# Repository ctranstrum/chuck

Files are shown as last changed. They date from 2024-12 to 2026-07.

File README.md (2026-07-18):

# Charlieflex Keyboard

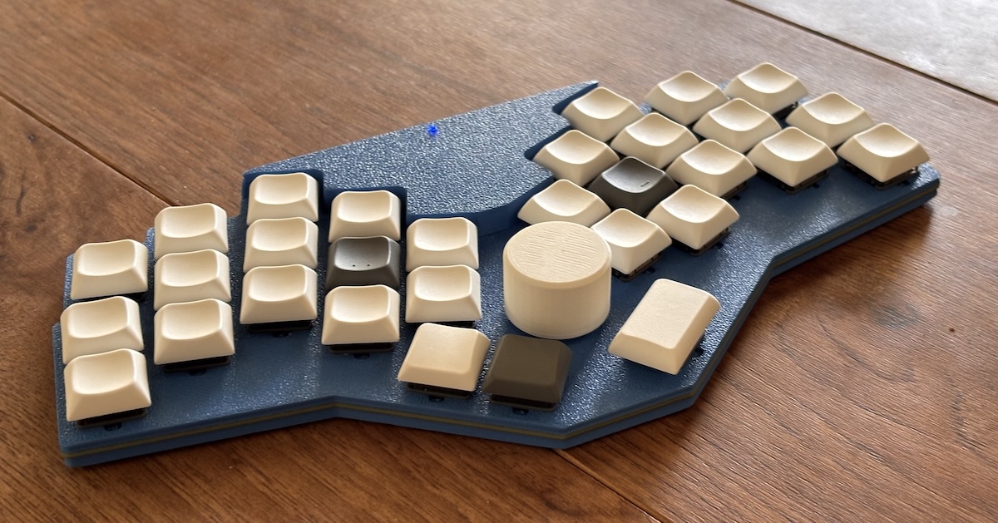
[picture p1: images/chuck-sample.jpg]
Charlieflex sample


## Features

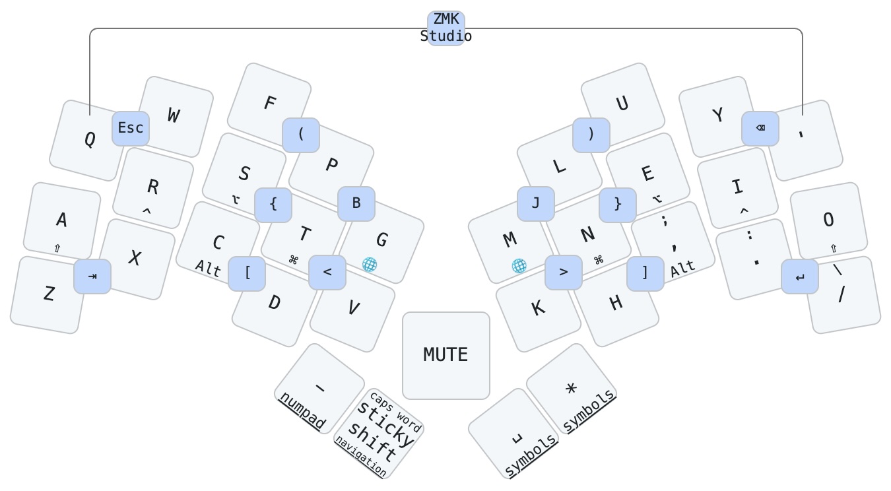
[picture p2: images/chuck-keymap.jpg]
Charlieflex keymap


- 30-32 key wireless ergo keyboard with aggressive pinky stagger and splay
- central rotary encoder can be used by either hand
- designed for the Seeed Studio [XIAO BLE][xiao] wireless microcontroller
  - also works with the [XIAO RP2040][rp2040] for a lower-cost wired board
- Choc v1 or v2 low profile hotswap switches to allow a wider range of keycap choices
- Unique tiered low-profile "snug sandwich" case with no exposed electrical components
- [RGB LED status][rgbled] visible on the top of the case
- Wireless-first design using [ZMK][zmk] [firmware][firmware] (including [ZMK Studio][studio])
- Internal space (5.5 x 27 x 32 mm) for a "large" 502530 300mAh battery
- [PCB](images/chuck-pcb.jpg) designed with [ergogen][ergogen] for easy modification
- Licensed under the [CERN Open Hardware License v2][ohl]
- All source files available, so you can tweak the design if needed

## Design goals

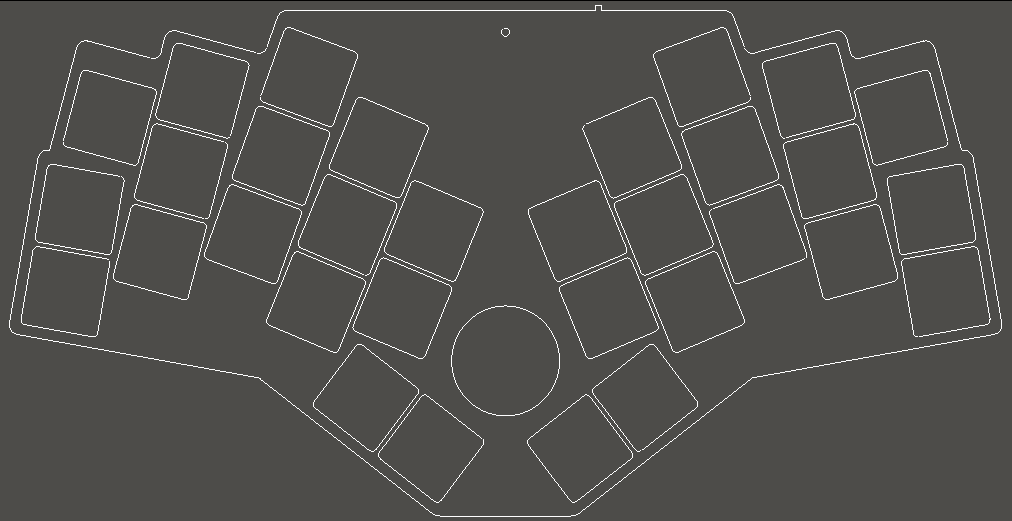
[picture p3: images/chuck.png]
Charlieflex Layout


- Low cost wireless
  - xiao ble is only $10 per controller compared to $25 for the nice!nano
  - Big battery and an option for a dongle, so you can run for months without recharging
  - xiao rp2040 is under $5 with no need to purchase a battery or power switch if you want a wired board
- Ergonomic unibody design for the ultimate comfort and easy portability
  - each half is angled to match the angle of the hands on the board
  - keys are placed where fingers naturally fall, with no excessive stretching
    - 1DFH: no finger has to move farther than 1 key's distance from its home row position
    - when fingers extend, they splay, so the keys also splay outward to follow the fingers
    - the pinky is shorter than the other fingers, so the pinky keys are placed lower to match, and the top pinky key is traded for a ring finger key
    - the inner column of each hand is reduced to two keys to eliminate the need for index finger stretching
    - each thumb gets a single key, with an option for a secondary thumb key if your thumbs are smarter than mine
  - centrally located rotary encoder knob for easy ambidextrous access to scrolling and volume control
  - includes all source files, so if your fingers are slightly different, with a little work you can adjust the keyboard to fit you exactly

finger map

- Low profile [3D printable case][case]
  - wireless case is only about 7mm high in front and 15mm high in the back, and comes in three separate pieces, each largely flat on one side for easy FDM printing with minimal fuss
  - for those who don't want or need the extra space required for a battery, a separate wired case is provided, which comes in two pieces and is just under 7mm tall
  - options for 1 or 2 thumb keys on each hand so you can go minimal if desired
  - smaller versions are included for smaller print beds
  - a few different [knobs][case-knob] are included so you can get the height that works best for you
  - bumpons are inset into the case 1mm to minimize their height; they add only 1/2mm in height
- Hotswappable
  - keycaps and switches can be easily removed and exchanged so you can fine-tune the feel
  - ability to move back and forth between or even mix and match choc v1 and choc v2
- Electrostatic mitigation
  - unlike many other ultra-low-profile cases, no electronics are left exposed
  - usb port and power switch are on the back, reset switch is recessed into the bottom of the case

## Build Guide

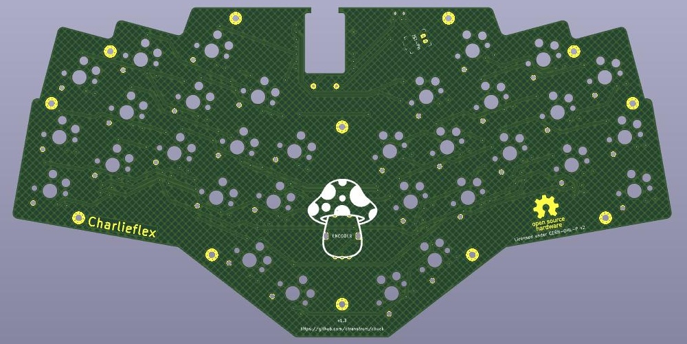
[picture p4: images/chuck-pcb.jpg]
Charlieflex PCB


Interested in building a Charlieflex of your own?
Check out the [Build Guide][guide] for details.

## Ancestry

I designed the [Lintilla keyboard][lintilla] before the Charlieflex,
but over time I realized that I didn't actually like split keyboards with separate halves,
because I move around a bit as I type so I either have to keep adjusting the position
of each half, or I end up contorting my wrists to align with the keyboard.

I also came to the conclusion that I would be better off with fewer pinky keys,
due to the strain of reaching with the pinky, and my thumbs aren't actually
smart enough for three keys each.

However, the basic layout of the remaining keys didn't change much from what
I had before, so if you want a split layout and more keys than the Charlieflex offers,
maybe the [Lintilla][lintilla] is for you.

## Descendants

I found some issues with running a charlieplex matrix on a wireless board where
battery levels can impact the performance of the diodes, which need very precise
cutoffs to interpret the keys being pressed; it made some of my 3-key combos a little
unreliable in practice.

So I went back to the drawing board and discovered an extra two usable pins on the xiao ble.
Using those allowed me to build the [Patagona gigas][patagona], with 32 keys and a five-way switch,
along with the [Patagona chaski][patagona], with 42 keys,
the same number of keys used by the [Lintilla][lintilla].

## Builds

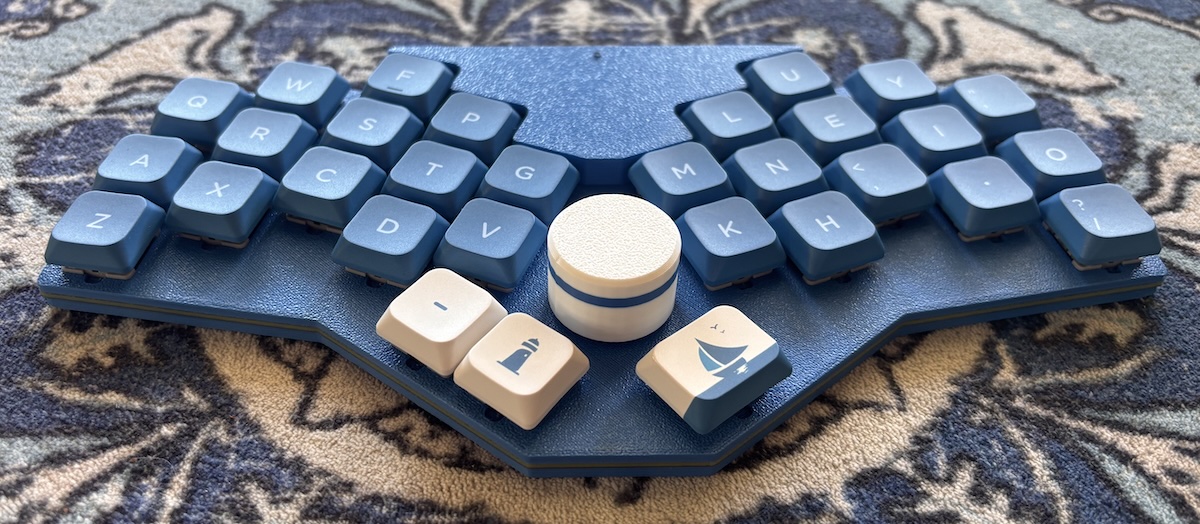
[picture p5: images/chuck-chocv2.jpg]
Charlieflex Choc v2 Keyboard


My Charlieflex, in the Twentyone Chuck Street layout, with 2 keys for the left thumb and one key for the right.
I'm using [Lofree Hades Choc v2 switches][hades]
and [Nuphy Shiokaze nSA keycaps][shiokaze].

---

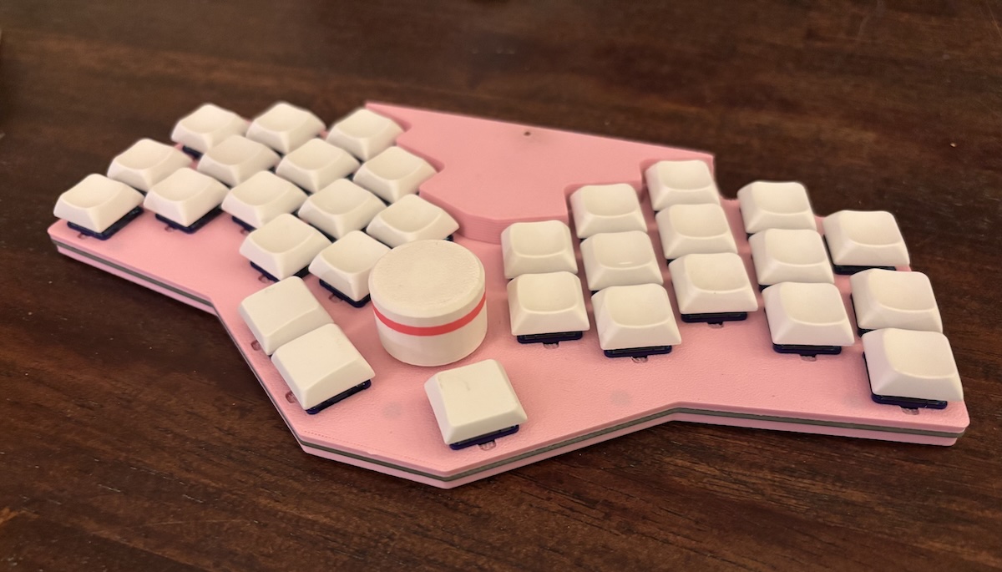
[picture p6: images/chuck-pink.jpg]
Charlieflex Choc v1 Keyboard


I also built a pink Charlieflex for the office,
this time with [LDSA keycaps][ldsa]
on [Bokeh Ambient Choc v1 switches][bokeh].

---

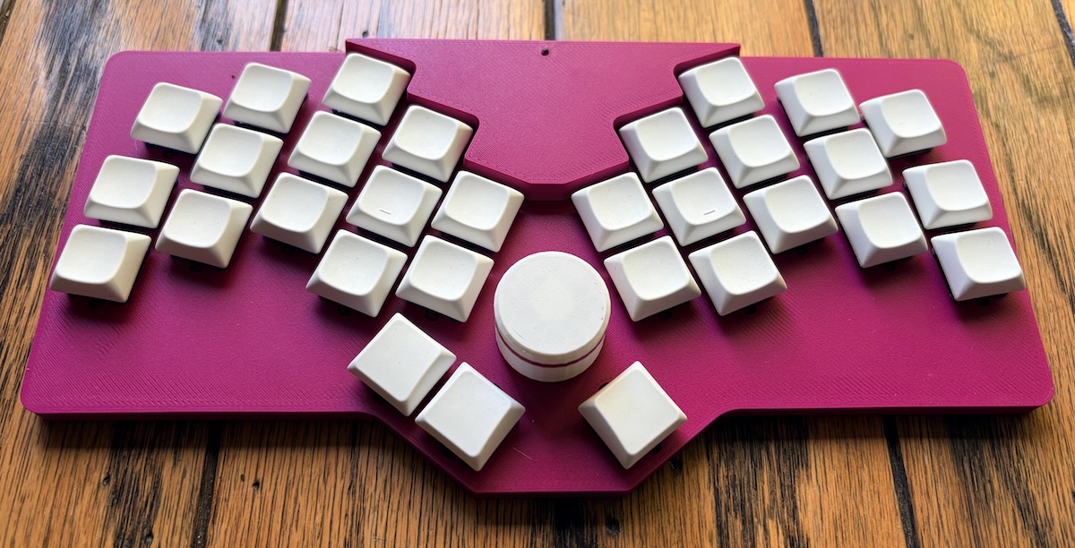
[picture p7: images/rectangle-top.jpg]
Charlieflex keyboard with rectangle case


An alternate snap-fit case that uses fewer screws and is a bit more stable
if you tend to use the keyboard directly on your lap.

[ergogen]: https://ergogen.xyz
[bokeh]: https://lowprokb.ca/products/ambients-silent-choc-switches?variant=51042310062244
[case]: cases#readme
[case-knob]: cases#encoder-knobs
[firmware]: https://github.com/ctranstrum/chuck/tree/zmk
[guide]: BUILD.md
[hades]: https://www.lofree.co/products/hades-low-profile-pom-switches
[ldsa]: https://lowprokb.ca/collections/keycaps/products/ldsa-low-profile-blank-keycaps
[lintilla]: https://github.com/ctranstrum/lintilla
[ohl]: LICENSE.txt
[patagona]: https://github.com/ctranstrum/patagona
[rgbled]: https://github.com/caksoylar/zmk-rgbled-widget
[rp2040]: https://www.seeedstudio.com/XIAO-RP2040-v1-0-p-5026.html
[shiokaze]: https://nuphy.com/collections/keycaps/products/shiokaze-nsa-dye-sub-pbt-keycaps
[studio]: https://zmk.dev/docs/features/studio
[twilight]: https://lowprokb.ca/products/ambients-silent-choc-switches?variant=44873426436260
[xiao]: https://wiki.seeedstudio.com/XIAO_BLE/
[zmk]: https://zmk.dev

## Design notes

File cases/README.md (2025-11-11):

# Charlieflex Cases

> A quick note: these files were created through ergogen and can be
> modified and re-created if any changes are needed, which is great,
> except that the software is still a little bit buggy, so it doesn't
> make perfect STL files. Even though these can look a little strange,
> I have printed all of these files and they came out okay for me.

## Keyboard case files

### Full size printer

If you have access to your own 3D printer with a large print bed
or if you are sending the files away to be printed,
you will want to use the full size cases:

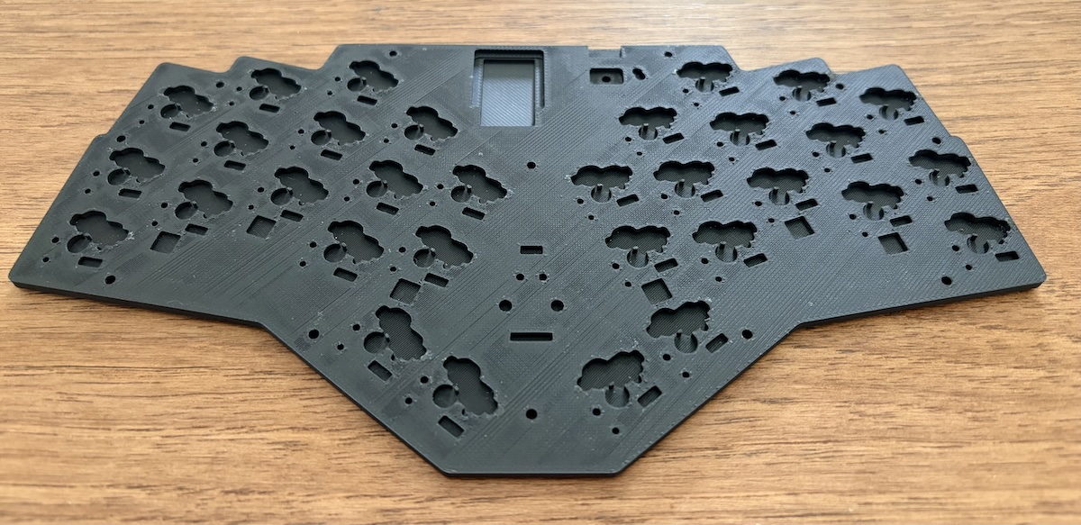
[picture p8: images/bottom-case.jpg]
bottom-case


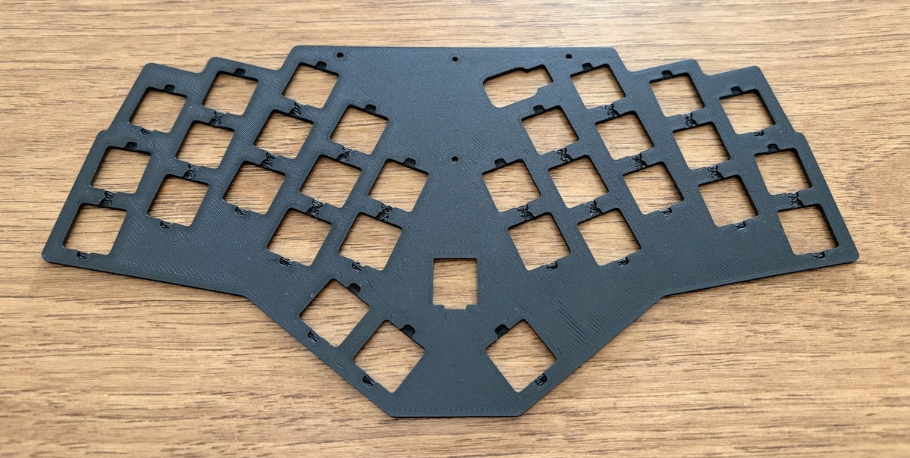
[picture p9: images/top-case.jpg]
top-case


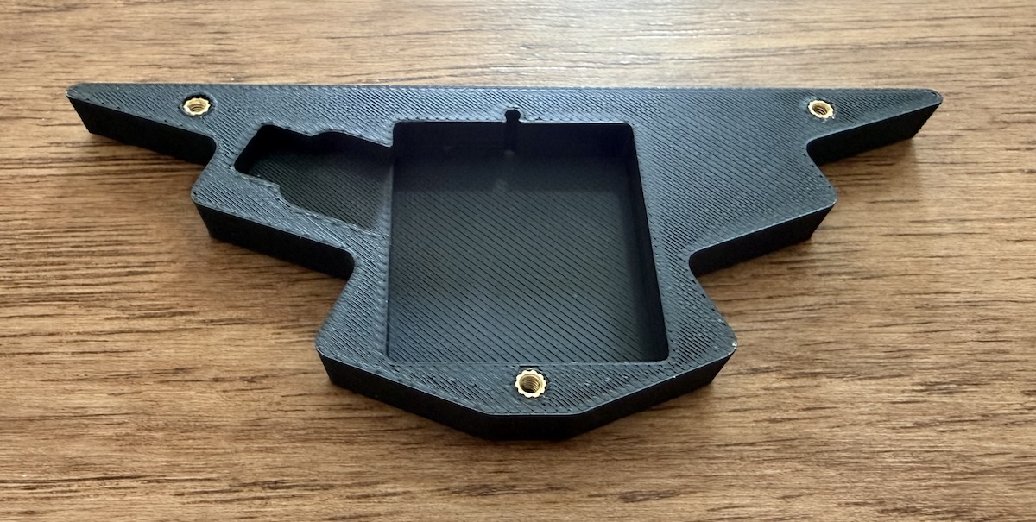
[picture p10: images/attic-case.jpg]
attic-case


| wired | wireless | description |
| --- | --- | --- |
| [bottom](wired_bottom_case.stl) | [bottom](bottom_case.stl)  | installed below the PCB |
| [top](wired_top_case.stl) | [top](top_case.stl) | installed above the PCB for two thumb keys on each side |
| | [battery cover](attic.stl) | above the top plate (do not print in resin) |

There are three alternative top cases that can be used
depending on the number of thumb keys used on each hand:

| wired | wireless | description |
| --- | --- | --- |
| [one up chuck](wired_top_case_one_up_chuck.stl) | [one up chuck](top_case_one_up_chuck.stl) | one thumb key on each hand |
| [twentyone chuck street](wired_top_case_twentyone_chuck_street.stl) | [twentyone chuck street](top_case_twentyone_chuck_street.stl) | two thumb keys on the left hand and one on the right |
| [chucker by the dozen](wired_top_case_chucker_by_the_dozen.stl) | [chucker by the dozen](top_case_chucker_by_the_dozen.stl) | one thumb key on the left hand and two on the right  |

Note that for best results on an FDM printer, the top plate and the battery cover should be printed upside down.

### Mini printer

If you have access to your own 3D printer
but it has a print bed too small for the full-size case,
you can print the 3-part (plus the battery cover for wireless builds) top case:

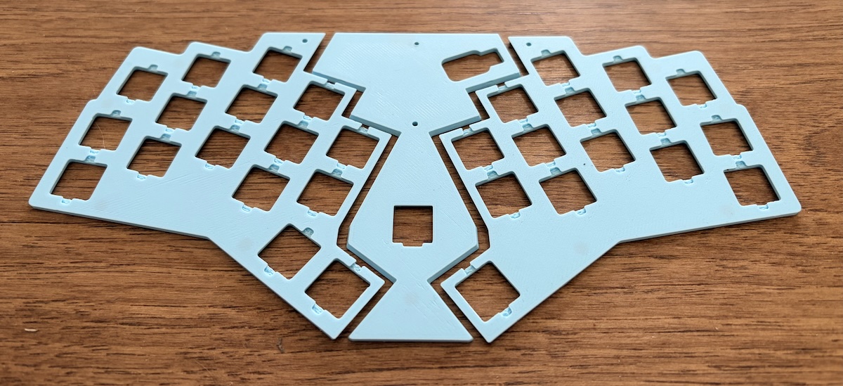
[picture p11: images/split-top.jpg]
split-top


| wired | wireless | description |
| --- | --- | --- |
| [center](wired_top_dovetail.stl) | [center](top_dovetail.stl) | center dovetail piece |
| [left 1](wired_top_dovetail_left_1.stl) | [left 1](top_dovetail_left_1.stl) | left piece with one thumb key |
| [left 2](wired_top_dovetail_left_2.stl) | [left 2](top_dovetail_left_2.stl) | left piece with two thumb keys |
| [right 1](wired_top_dovetail_right_1.stl) | [right 1](top_dovetail_right_1.stl) | right piece with one thumb key |
| [right 2](wired_top_dovetail_right_2.stl) | [right 2](top_dovetail_right_2.stl) | right piece with two thumb keys |
| | [battery cover](attic.stl) | above the top plate to cover the battery (do not print in resin) |

Note that these top cases should be printed upside down for best results on an FDM printer.

The bottom case is broken into two pieces:

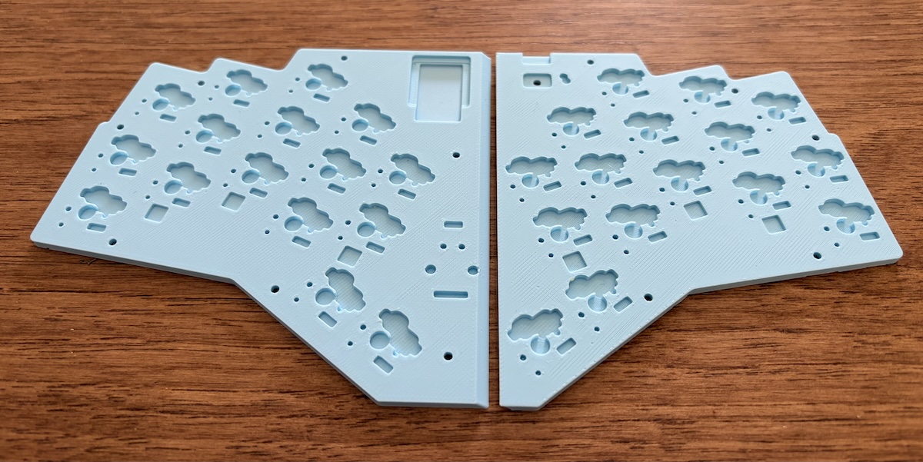
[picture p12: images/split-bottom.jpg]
split-bottom


| wired | wireless | description  |
| --- | --- | --- |
| [left](wired_bottom_dovetail_left.stl) | [left](bottom_dovetail_left.stl) | left bottom  |
| [right](wired_bottom_dovetail_right.stl) | [right](bottom_dovetail_right.stl) | right bottom |

### Rectangular snap-fit case

I've also created an alternative case that uses fewer screws and instead relies on a snap-fit design
to remain securely fastened without sacrificing any additional height compared to the original sandwich design.

rectangle-top

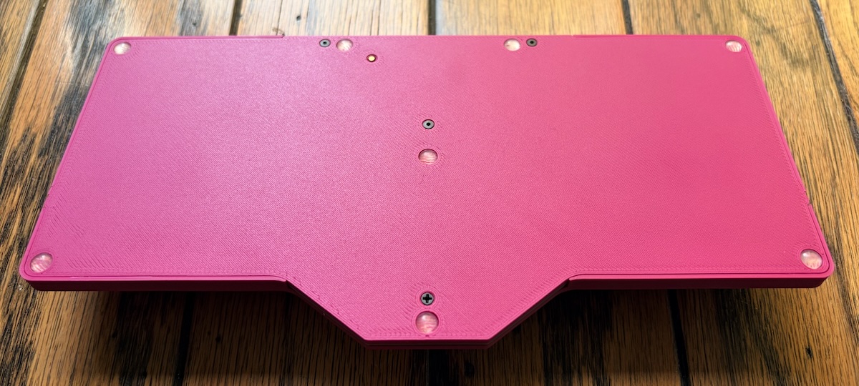
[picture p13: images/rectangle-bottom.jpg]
rectangle-bottom


Unlike the sandwich-style cases, it is available only for full-size printer beds,
and only for a wireless build.

| wireless | description |
| --- | --- |
| [bottom](rectangle_bottom_case.stl) | bottom case |
| [top](rectangle_top_case.stl) | top case option with two thumb keys on each hand |
| [one_up_chuck](rectangle_top_case_one_up_chuck.stl) | top case option with one thumb key on each hand |
| [twentyone_chuck_street](rectangle_top_case_twentyone_chuck_street.stl) | top case option with two left thumb keys and one right thumb key |
| [chucker_by_the_dozen](rectangle_top_case_chucker_by_the_dozen.stl) | top case option with one left thumb key and two right thumb keys |
| [battery cover](attic.stl) | above the top case to cover the battery (do not print in resin)  |

Note that it is especially important when printing this case style on an FDM printer to place the top case
upside down in the slicer so that the top surface of the case is in direct contact with the print bed.
Otherwise you are going to have a real struggle with support removal.

## Print quality hints

When printing this case,
it should be noted that the battery cover (filename: `attic.stl`) is designed
to have heat-set inserts melted into it,
so it is not recommended to print using a resin printer
or using a material that cannot be melted easily,
unless you plan on altering the case design to use another method
to fasten the case together.

All other parts of the case can be printed in whatever material you like.

For FDM printing,
the top case and the attic are best printed upside down,
so that the visible part of the case is against the print bed,
giving the best top surface and requiring minimal supports to print.

If you are having trouble with some of the raised areas sagging during printing,
you can try to enable supports.
While I was able to tune my printer to get great results without supports,
if your printer is not well calibrated,
it may be worth it to enable supports and spend a little time
post-processing the prints to remove the supports prior to assembly.

## Encoder knobs

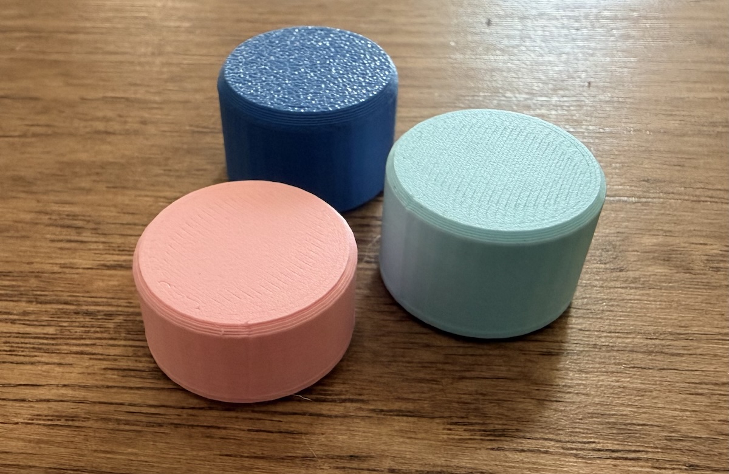
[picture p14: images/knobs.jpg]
knobs


The keyboard was designed with the idea of using a 25mm diameter knob,
but I had a hard time finding encoder knobs that size,
especially for an EC12 low-profile encoder.

If you use the recommended EC11 encoder,
you should have plenty of commercially available options for the knob,
so feel free to use whatever knob you like.

But I've also created a super-simple one with a skirt
so that as much of the encoder as possible is hidden.

- [ec11_encoder_knob.stl](ec11_encoder_knob.stl)
- [ec12_encoder_knob.stl](ec12_encoder_knob.stl)

Both of those knobs will give about the same look,
but if you use a low-profile EC12 knob,
you have the ability to go with a shorter knob:

- [encoder_knob-15mm.stl](encoder_knob-15mm.stl)
- [encoder_knob-13mm.stl](encoder_knob-13mm.stl)
- [encoder_knob-10mm.stl](encoder_knob-10mm.stl)

All of the encoder files can be printed as-is with no supports.

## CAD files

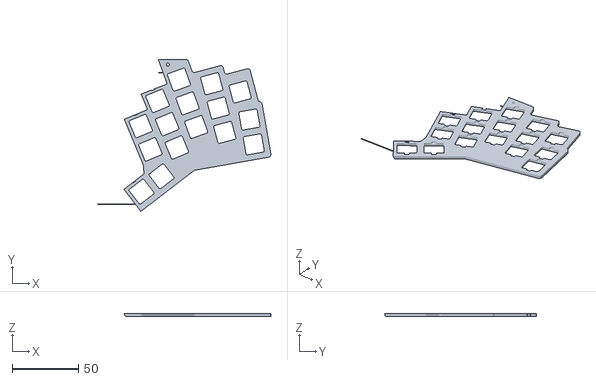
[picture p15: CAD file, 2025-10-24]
cases/top_dovetail_right_2.stl
163.7 x 114.5 x 2.20

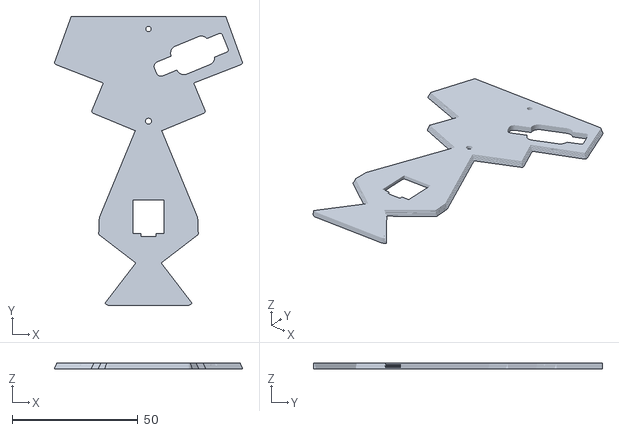
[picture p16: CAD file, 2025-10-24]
cases/top_dovetail.stl
74.7 x 114.9 x 2.20

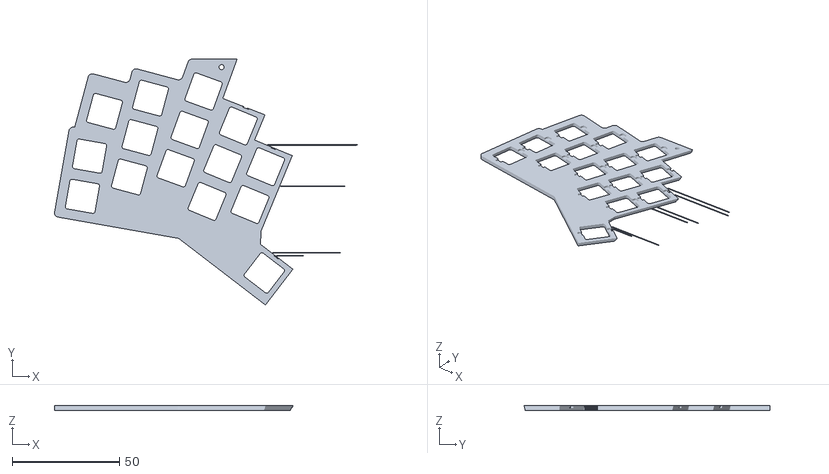
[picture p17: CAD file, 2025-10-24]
cases/top_dovetail_left_1.stl
165.7 x 114.5 x 2.20

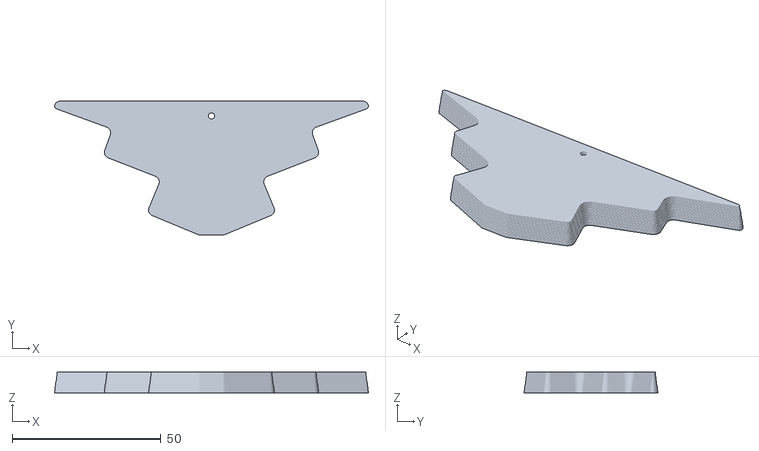
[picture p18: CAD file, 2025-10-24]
cases/attic.stl
105.5 x 45.0 x 7.00

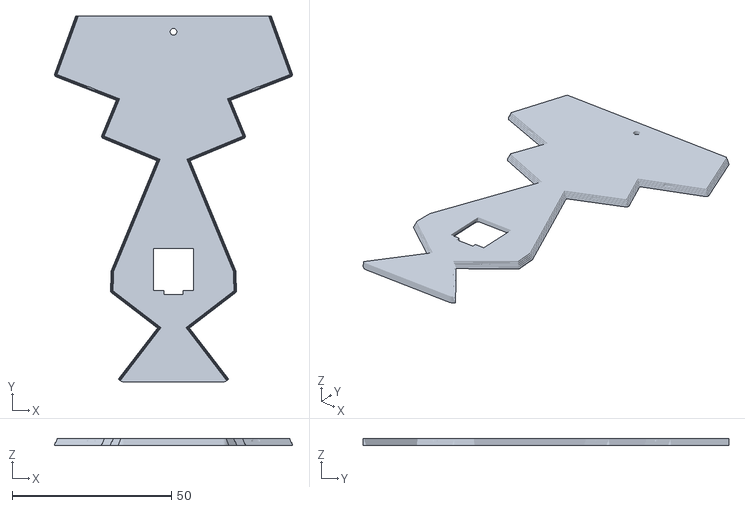
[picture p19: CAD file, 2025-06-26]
cases/wired_top_dovetail.stl
74.7 x 114.9 x 2.20

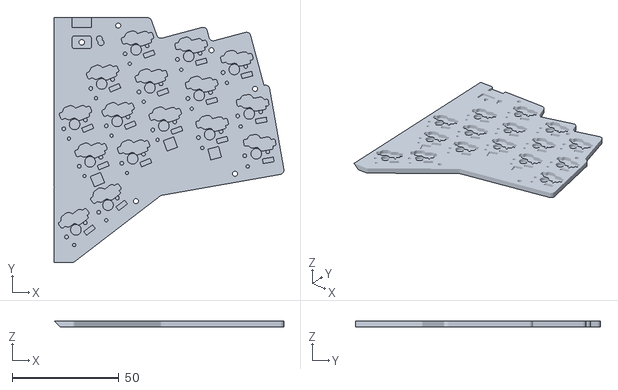
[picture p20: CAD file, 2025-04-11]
cases/bottom_dovetail_right.stl
107.9 x 114.9 x 3.00

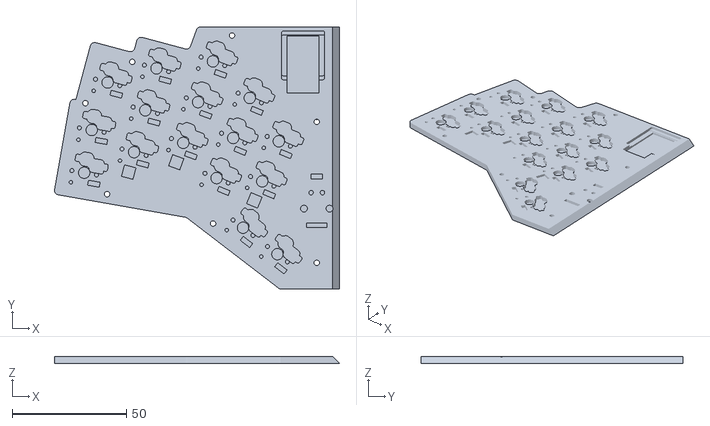
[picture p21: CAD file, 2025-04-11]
cases/bottom_dovetail_left.stl
124.8 x 114.9 x 3.00

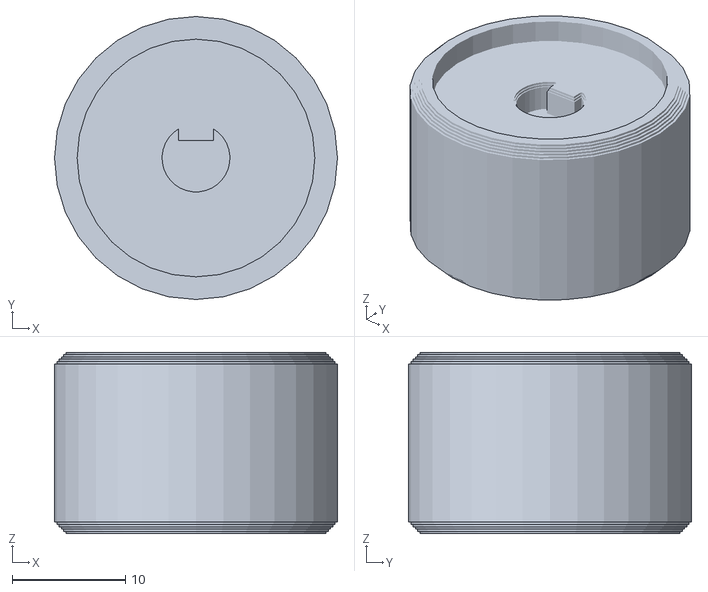
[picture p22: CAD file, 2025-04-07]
cases/ec12_encoder_knob.stl
25.0 x 25.0 x 16.0

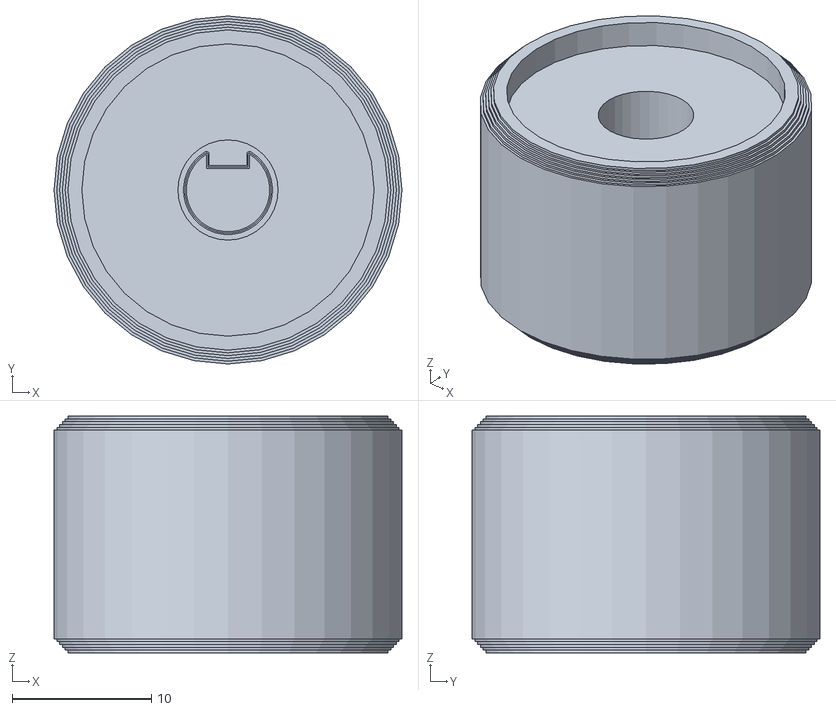
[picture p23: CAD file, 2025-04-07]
cases/ec11_encoder_knob.stl
25.0 x 25.0 x 17.0

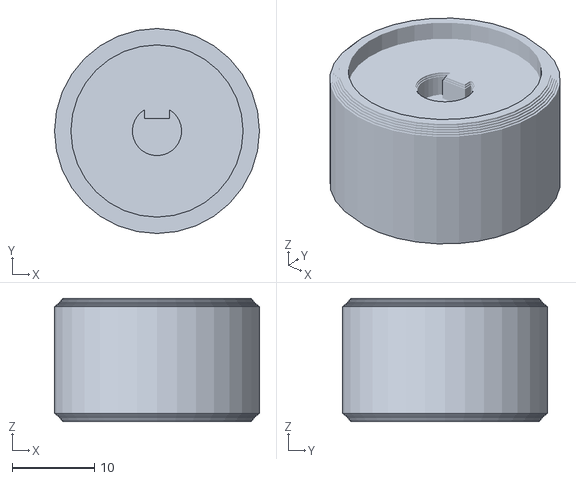
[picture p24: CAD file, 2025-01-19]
cases/encoder_knob-15mm.stl
25.0 x 25.0 x 15.0

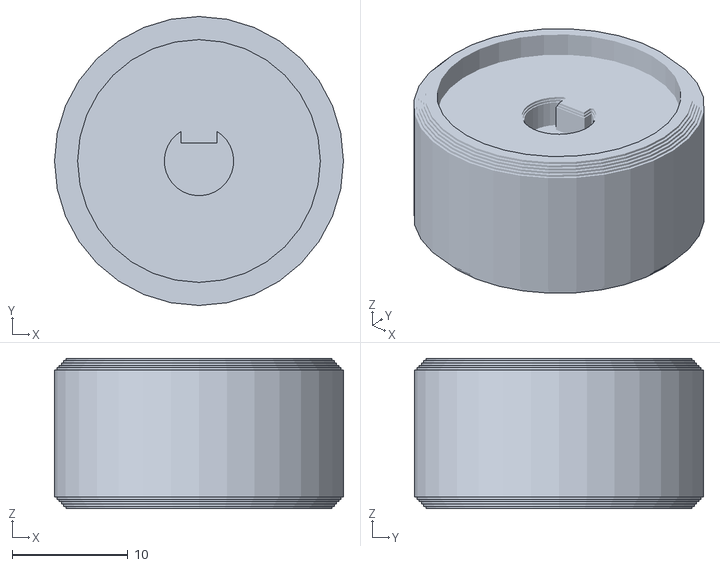
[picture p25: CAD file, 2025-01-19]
cases/encoder_knob-13mm.stl
25.0 x 25.0 x 13.0

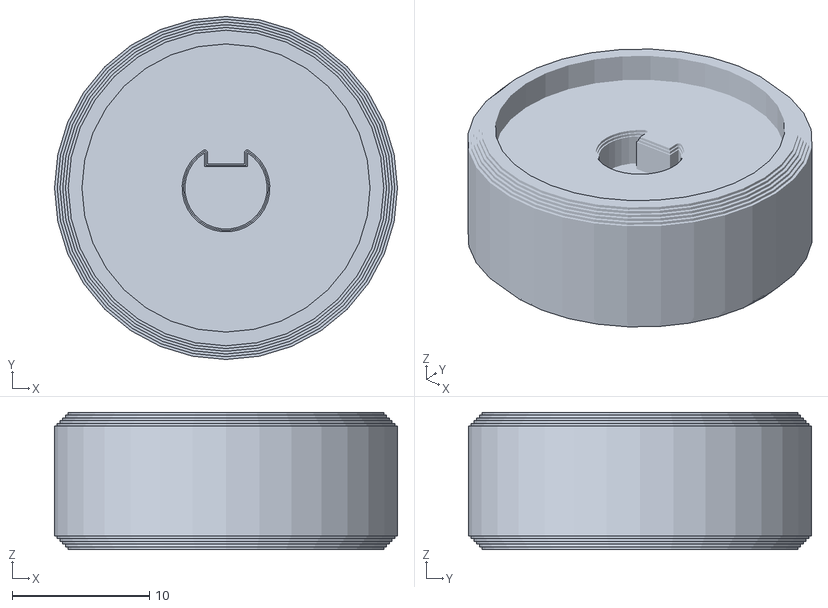
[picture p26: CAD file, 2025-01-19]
cases/encoder_knob-10mm.stl
25.0 x 25.0 x 10.0

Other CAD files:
cases/top_dovetail_left_2.stl
cases/top_dovetail_right_1.stl
cases/wired_top_dovetail_left_2.stl
cases/wired_top_dovetail_right_1.stl
cases/wired_top_dovetail_left_1.stl
cases/wired_top_dovetail_right_2.stl

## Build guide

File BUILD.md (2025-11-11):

# Charlieflex Build Guide

If this is your first time building a custom keyboard,
you should do two things before attempting this build.

- watch a few [soldering][how-to-solder] [tutorials][soldering101]
- read through a detailed build guide like
  the one for the [splitkb.com Aurora Series][splitkb-build-guide]

The remainder of this build guide will assume a basic familiarity with the process
and will only hit upon specific items that may be different or important to note while
building the Charlieflex.

## Bill of materials

| Wireless Qty | Description | Wired Qty |
| --- | --- | --- |
| 1 | [Charlieflex PCB][pcb] (can be printed by uploading the [zip file][gerber] to [JLC][jlcpcb]) | 1 |
| 3 | [3D printed cases][case] | 2 |
| 1 | [XIAO BLE][xiao] | |
| | [XIAO RP2040][rp2040] | 1 |
| 1 | [SMD 5x5x3 tactile switch][reset] for the reset button (similar to [this][pts526] or [this][ts18]) | 1 |
| 1 | [Alps SSSS811101 SPDT slide switch][power] for the battery on/off | |
| 1 | [3.7v 300mAh 502530 LiPo battery][battery] or smaller (max internal space: 5.5x27x32mm) | |
| 1 | [JST PH-2 battery jack][jst] | |
| 45 | SOD-123 [1N4148W SMD diodes][sod123] | 45 |
| 30-32 | Kailh [choc hot swap sockets][sockets] | 30-32 |
| 30-32 | [Choc v1][chocv1] or [v2 switches][chocv2] of your choice | 30-32 |
| 30-32 | [Low profile choc v1][chockeycaps] or [v2 keycaps][mxkeycaps] of your choice | 30-32 |
| 1 | Bourns [PEC11L-4115F-S0020][encoder]\* EC11 encoder with a [knob][case-knob] of your choice | |
| | Bourns [PES12-42S][smallencoder] low profile EC12 encoder with a [knob][case-knob] of your choice  | 1 |
| 9 (1) | [M2 x 6mm countersunk screws][screws6mm] | 12 |
| 9 (1) | [M2 hex nuts][hexnuts] | 12 |
| 3 | [M2 x 10mm countersunk screws][screws10mm] | |
| 3 | [M2 heat-set inserts 3mm x 3mm][heatset] | |
| 10 (8) | [6mm x 1.5mm bumpons][bumpons] | 10 |
| ~1cm | [1.75mm transparent 3D printer filament][filament] for the "fiber optic" led light guide | ~3mm |
| 2 | short (1-2cm) piece of [26 gauge electrical wire][wire] | 1 |

\* You can use a different encoder from another manufacturer if you aren't going wireless,
but the specified wireless encoder listed in the bill of materials
is designed to have its detents with both A and B set to low,
so a different option is likely to draw more power,
and thus isn't the best choice for a wireless build.

**Note**: When assembling a Charlieflix build in a rectangle case, you will use fewer 6mm screws, hex nuts, and bumpons.
The quantities for the rectangle case are given in parentheses.

## Useful equipment

You will need:

- a [soldering iron][pinecil]
- some [good quality solder][kester]
- precision tweezers
- wire cutter / stripper

You should ideally have access to:

- a [heat-set insert tool][heatsettool]
- a decent hands-free magnifying glass
- isopropyl alcohol and an old toothbrush

## Getting the PCB

The PCB can be easily ordered from a circuit board manufacturer with an online store.
I used [JLC][jlcpcb] because--at least at the time of my order--their prices are unbeatable.

To order, you can simply upload the [gerber zip file][gerber] to their website,
accept all of the defaults, and wait a week or two for the boards to arrive.

However, the minimum order at JLC is 5 copies, so you'll likely end up
with 4 extra PCBs. I don't really have any advice for what to do with
the extras, but you maybe could give one to a friend!

A few items that you may want to customize:

- the color of the board; I printed mine in blue
- I also chose to hide the JLC order number, to give the board a cleaner look
- HASL can be lead-free if you are also using lead-free solder, or you can splurge for ENIG, but it's definitely not required

## Getting the case

If you have access to a 3D printer, the [case][case] is very easy to print yourself.
If you have a Bambu printer, I uploaded printer profiles to their [makerworld][bambu] website.

If you don't have your own printer, no worries.
You will probably want to send in your print order around the same time you order the PCB.
I've used [JLC][jlc3dp] in the past with good results.

Just remember that you should print the top-most piece of the case,
called "attic" in the [case list][case] and needed only for a wireless build,
in nylon or PLA rather than resin,
though all other parts of the case can be printed in resin.
The reason for this is that the design calls for heat-set inserts
to be melted into that piece, and resin doesn't work for that.

## General soldering order

Although you can work in any order you prefer,
I like to start with the smaller components, then move to the larger,
and finish with bulky items that go on the top of the board.

So, the order I install:

### Installed on the bottom of the board

- diodes
- hotswap sockets
- power switch
- reset switch
- xiao
- reset and battery wire connections to xiao

### Bulky items, assembled on the top of the board, but soldered on the bottom

- jst
- encoder

## Step-by-step instructions

Let's get started, shall we?

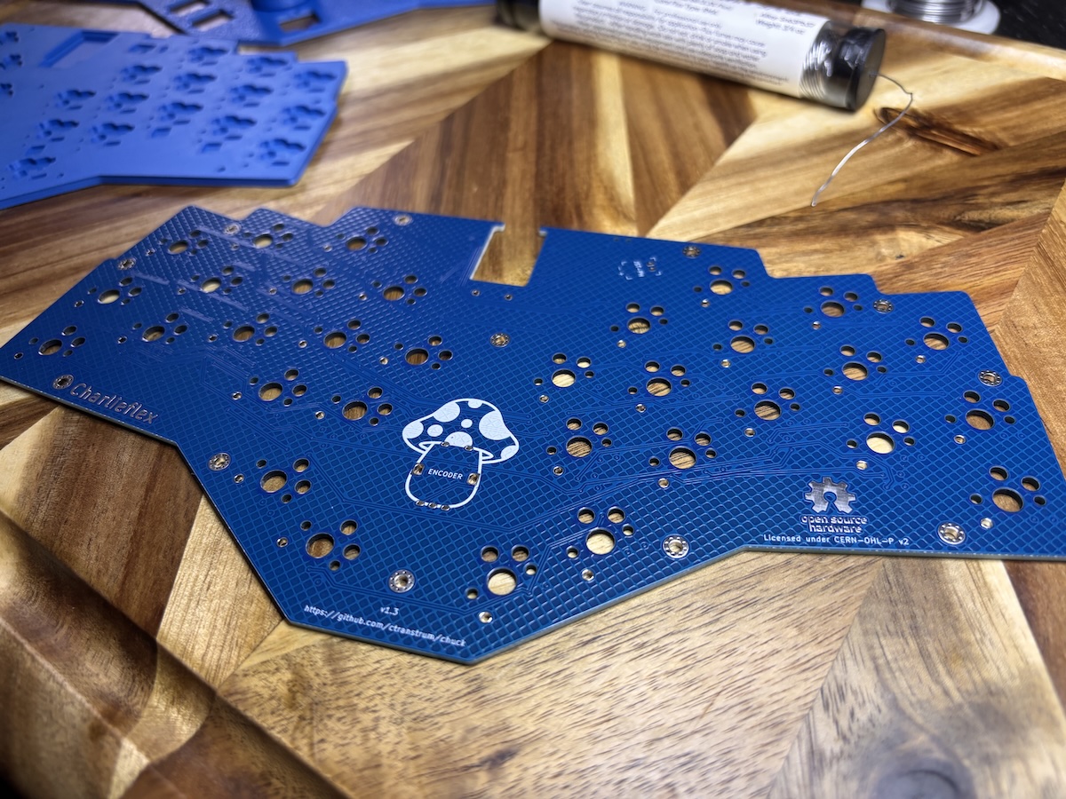
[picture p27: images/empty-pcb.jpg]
empty pcb


### Solder the diodes

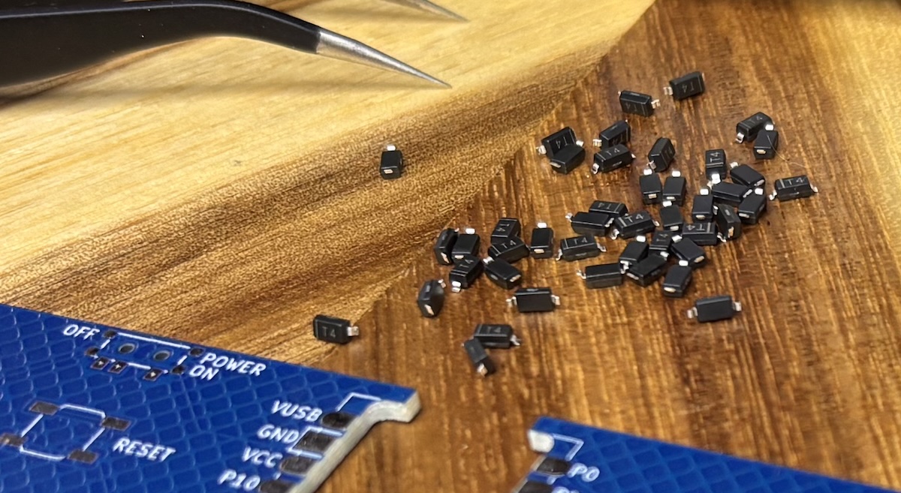
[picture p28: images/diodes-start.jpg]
start with diodes


Diodes are directional components, and must be soldered in the correct orientation.

To determine the orientation, look for a line printed on one edge of the diode.
You may need to use a magnifier glass and adjust the angle of light hitting the diode
in order to see it clearly.
Once you find the line on the diode, you can align it with the silk-screened line on the PCB,
and then solder with both lines on the same side.

All diodes are installed in roughly the same direction on the board, with the line on the right.

To easily install a diode, first place a small amount of solder onto one of the diode pads.

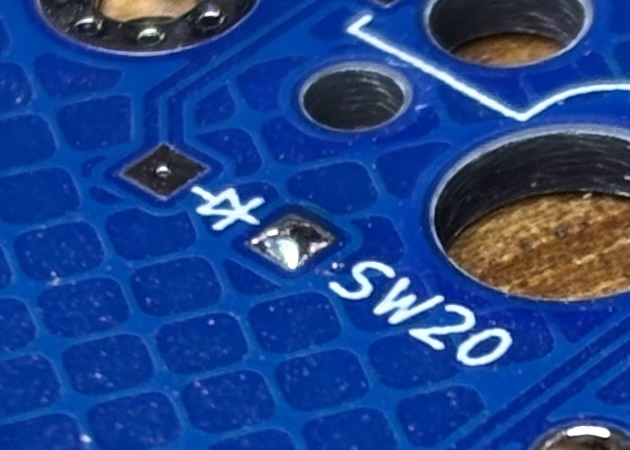
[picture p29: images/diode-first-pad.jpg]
first pad soldered


Then grab the diode with tweezers and orient it correctly.
Reheat the soldered pad, then slide the diode into place.
Remove the heat, and when the solder cools, release the diode.

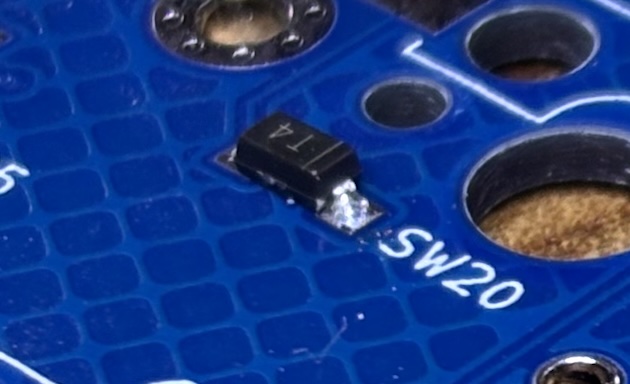
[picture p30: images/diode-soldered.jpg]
diode soldered


With one leg installed, you can apply solder to the other leg.

Complete all diodes, being sure to double-check that they are all oriented
correctly and both legs are soldered before moving to the next step.

### Solder the hotswap sockets

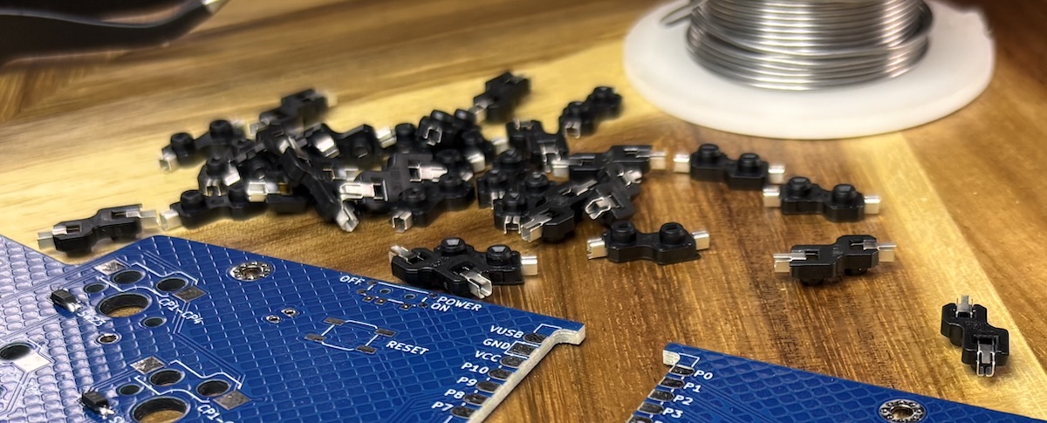
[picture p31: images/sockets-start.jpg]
start with sockets


While hotswap sockets will work the same way electrically no matter which way they are installed,
the tolerances of the case are such that you should take care to install these
according to the markings on the PCB as well.

Place the hotswap socket into the PCB holes,
being sure that the silkscreen on the PCB matches the orientation of the socket,
then apply solder to one of the legs.

This will take a lot more solder than the diode did, but be careful not to get carried away.
The solder should not overflow the pad or rise above the socket.

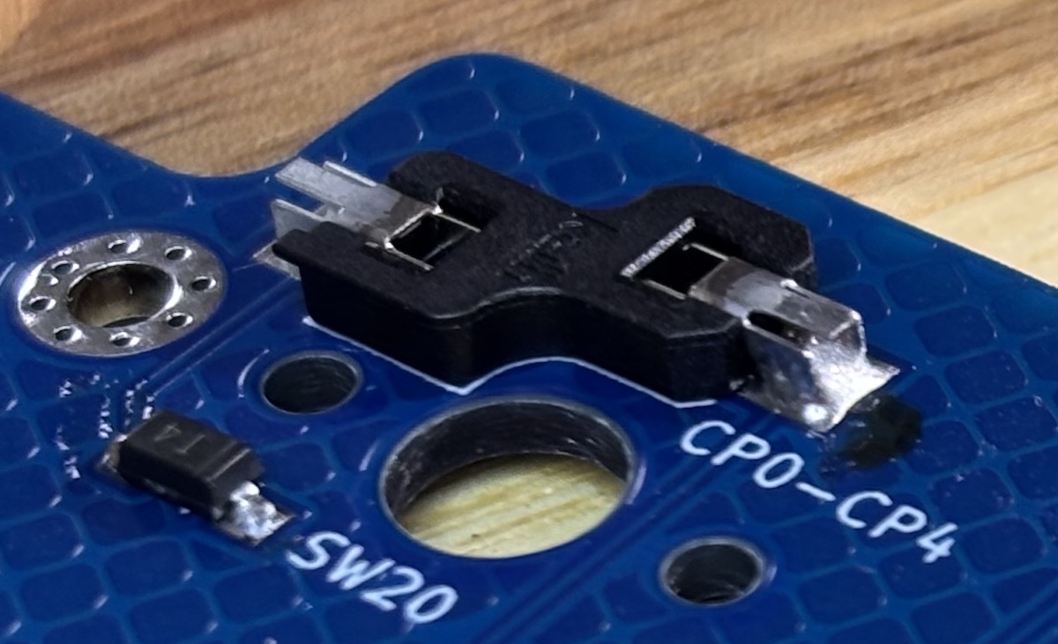
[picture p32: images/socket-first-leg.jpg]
first pad soldered


Once done, use tweezers to hold the socket in place until the solder cools.

Flip the board around and solder the other pad.

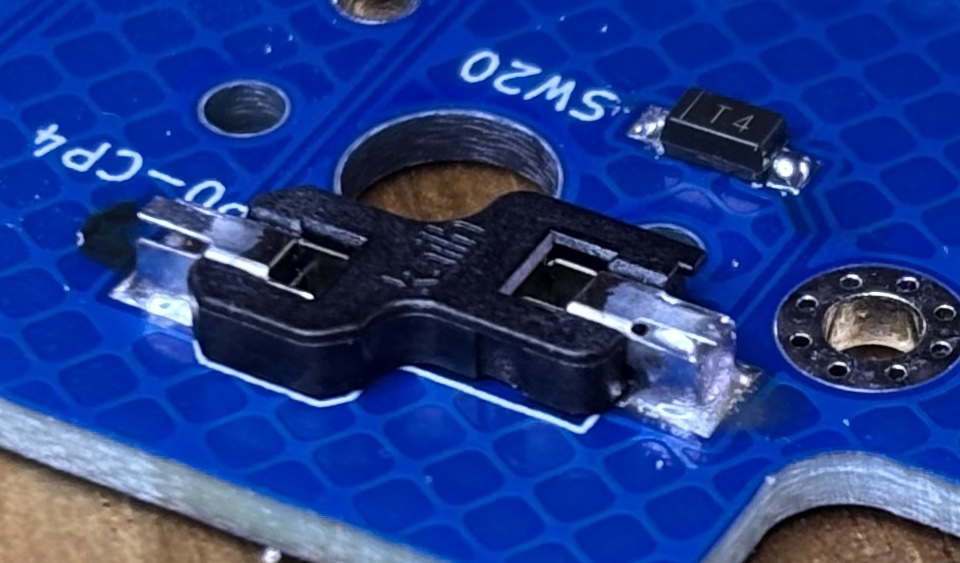
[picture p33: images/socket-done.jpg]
socket completed


Solder all the sockets on the board.

### Solder the power switch

_Note_: you should skip this step if you are not building a wireless keyboard.
A wired keyboard is powered by the USB from the computer,
so doesn't need a power switch.

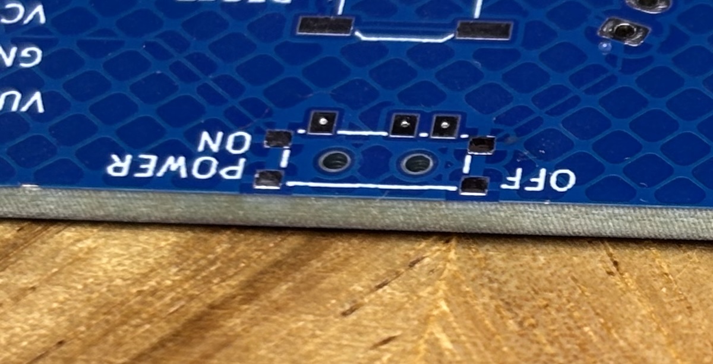
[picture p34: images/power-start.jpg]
start power


To solder the power switch, first apply a bit of solder to one of the pads.

Holding the power switch in place with tweezers, reheat the soldered pad
and align the power switch. Remove the heat, and release the power switch
only after the solder has cooled.

Once satisfied with the placement, solder each of the other pads, being very careful
not to allow the solder to connect neighboring pads.

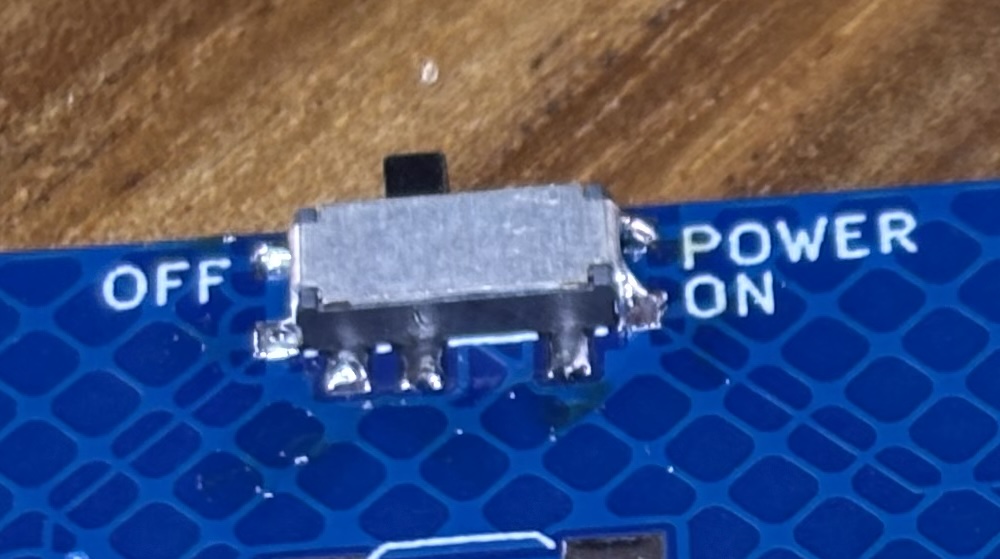
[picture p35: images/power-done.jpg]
power complete


### Solder the reset switch

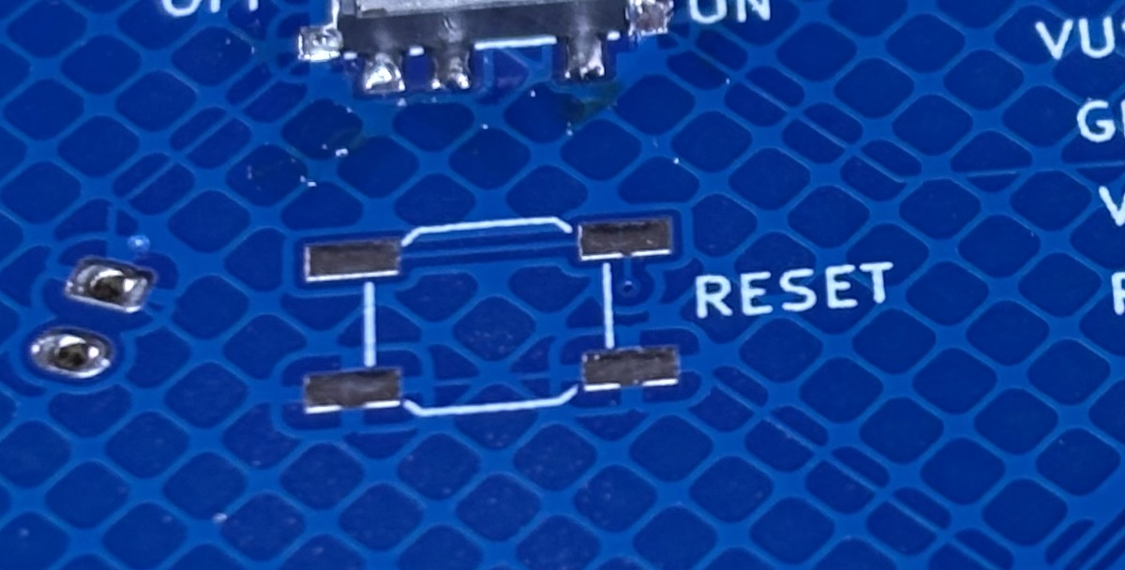
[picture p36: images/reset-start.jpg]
start reset


The reset switch follows the same process,
though it can require a little more attention to align it correctly.

Apply solder to one pad,
use tweezers to slide the reset switch into place while reheating the solder,
and remove the heat when you are satisfied with the alignment.

Complete the remaining pads.

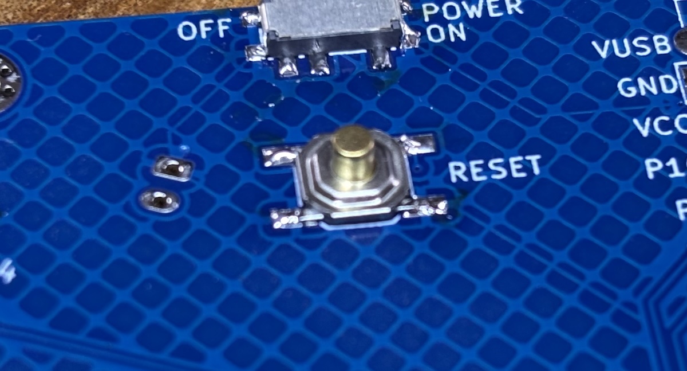
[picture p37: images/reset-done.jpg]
reset complete


### Solder the xiao

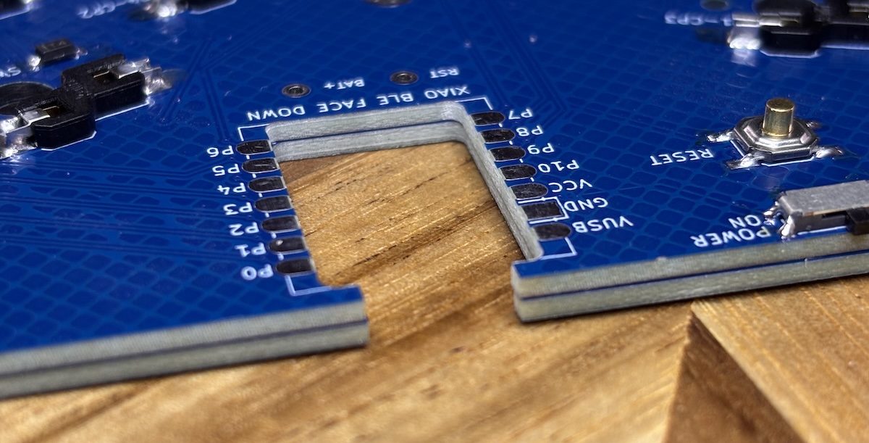
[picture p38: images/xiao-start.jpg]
start xiao


The xiao is installed upside down,
with the components on top of the xiao extending
into and beyond the space of the PCB.

Because of this, the xiao will need a little space under it,
since it is thicker than the PCB.
I like to stack another board below it to provide that space,
but any method of elevating the board will work.

Begin by placing a little solder on one of the corner pads.
Put the xiao in place, reheat the soldered pad,
and ensure the correct placement of the xiao before removing the heat.

Once the solder cools and you are satisfied that the xiao is in the correct place,
solder the opposite corner. It can be a little tricky to get heat on both the
pad of the PCB as well as the xiao's pad, so take your time, use plenty of heat,
and wait until you see the solder moving below the xiao and filling a bit of the
through-hole.

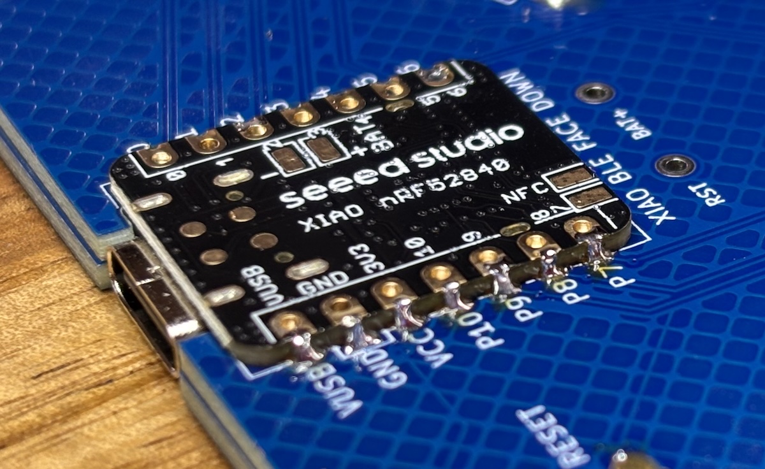
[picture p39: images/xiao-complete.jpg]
xiao complete


Repeat this process until all the pads of the xiao are soldered well to the board.
I also usually re-solder the first pad I did,
since it likely has the least amount of solder on it compared to all the others.

### Solder the xiao connections

_Note_: you should skip the BAT+ portion of this step if you are not building a wireless keyboard.
But be sure to solder the reset connection in the latter half of this step regardless.

Begin by cutting a short piece of wire a little bit longer than needed to connect the pad to the through-hole.

For the power connection, this connects the BAT+ hole on the PCB with the BAT+ pad on the back of the xiao.

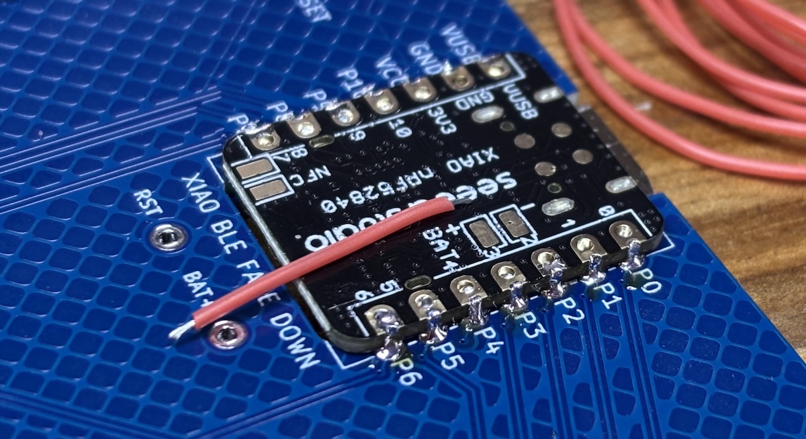
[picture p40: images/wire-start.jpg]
start power wire


Trim about 1.5mm of shielding off each end of the wire, and then solder the wire.
I like to start with the end on the xiao's pad, and once that is in place,
stick the other end into the through hole and solder there as well.

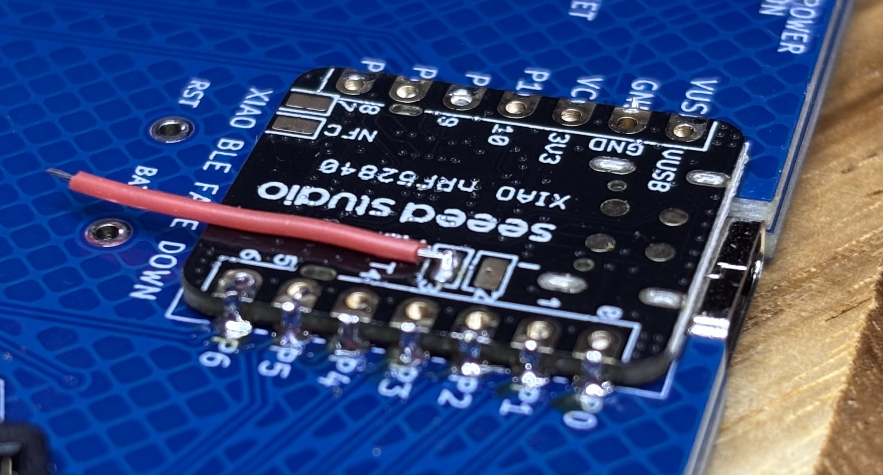
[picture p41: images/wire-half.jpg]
one half wire done


The reset button goes to from the RST hole on the PCB to the unlabeled reset pad on the back of the xiao.

Even though it's unlabeled, it's not difficult to find.
There are four circular pads near the USB port at the top of the xiao.

Location of the RST pad on the XIAO BLE:

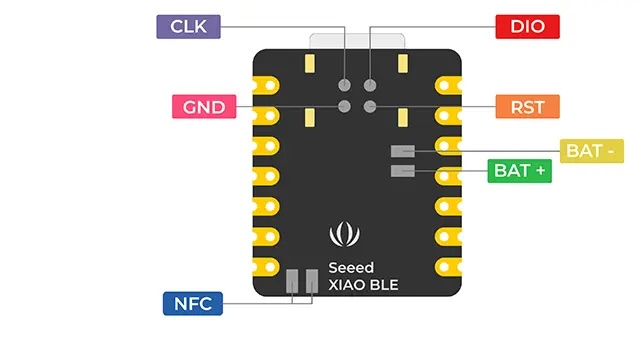
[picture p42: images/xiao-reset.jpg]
XIAO BLE RST pad


Location of the RST pad on the XIAO RP2040:

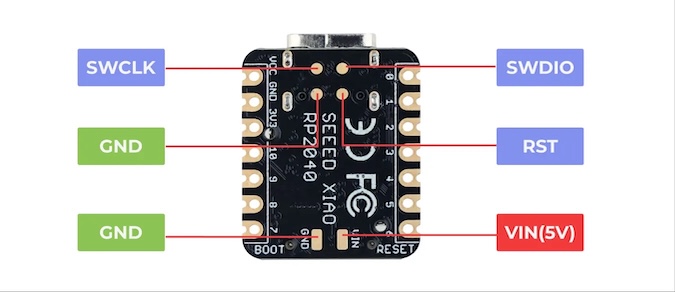
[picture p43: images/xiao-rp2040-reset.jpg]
XIAO RP2040 RST pad


Install it using the same method as the BAT+ wire.

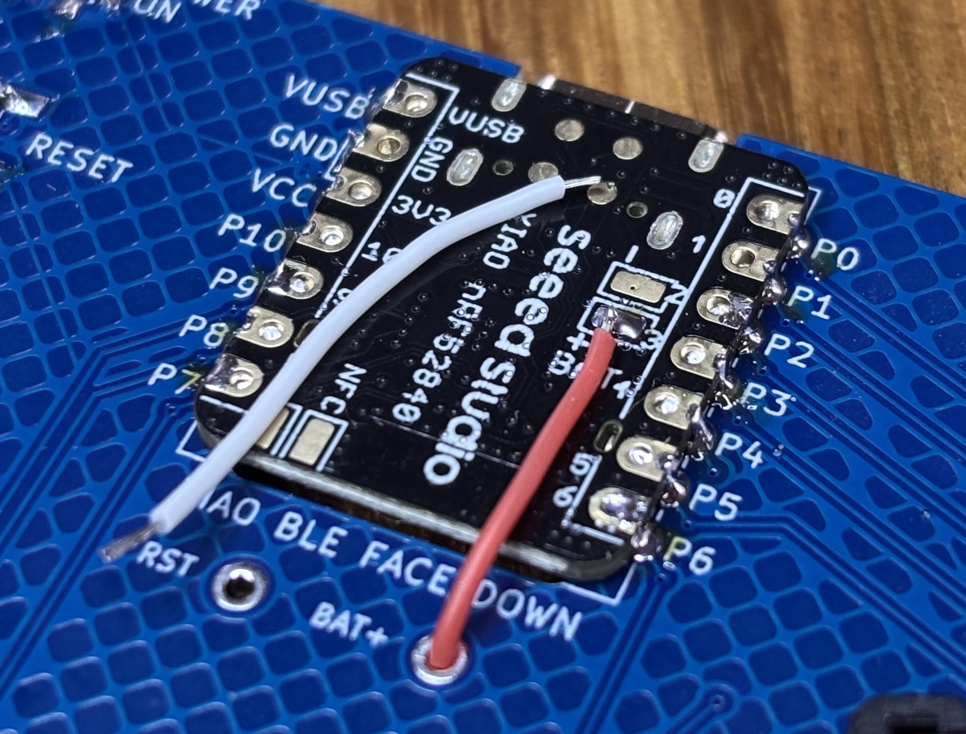
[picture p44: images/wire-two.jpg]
second wire


Cut the wire just a bit longer than the distance between the pad and the hole.
Remove the shielding about 1.5mm from each end,
and attach with solder in the same manner as the first.

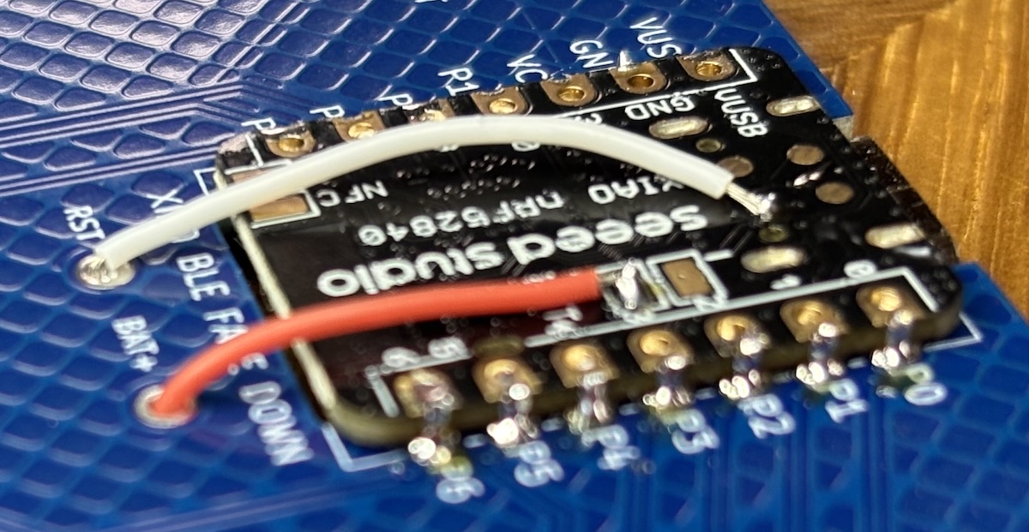
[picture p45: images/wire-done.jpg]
wire complete


### Solder the JST connector

_Note_: you should skip this step if you are not building a wireless keyboard.
The JST connector attaches the battery to the board, and is not used on a wired build.

Unlike all components so far,
the JST connector needs to be inserted into place from the opposite side of the board.

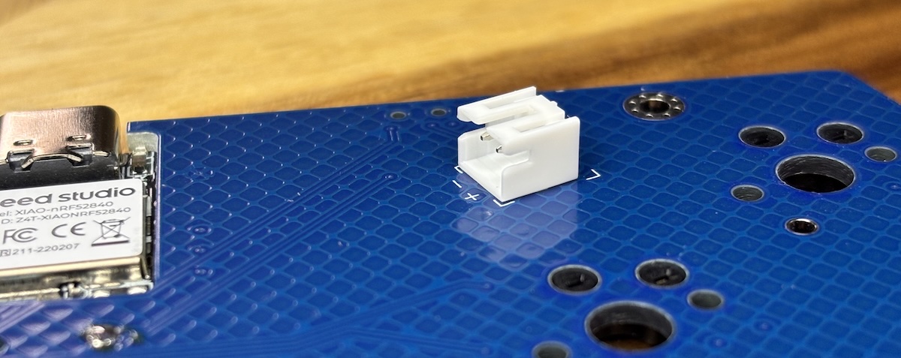
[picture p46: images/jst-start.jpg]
start jst


Once in place, secure it temporarily with a little tape
while you solder the legs on the other side of the board.

Remove the tape when done.

### Solder the encoder

The encoder also needs to be inserted from the opposite side of the board.

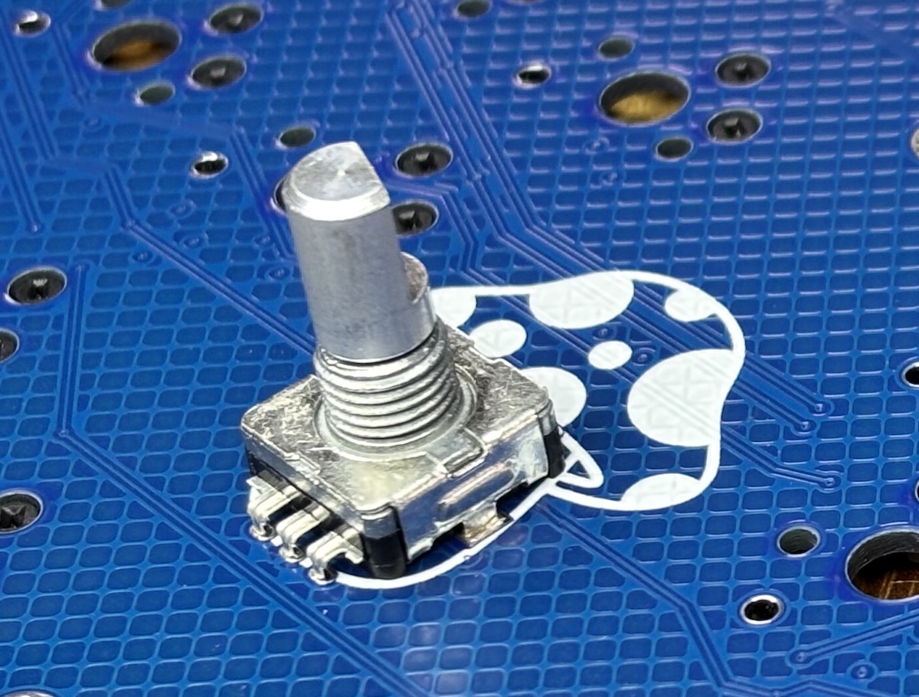
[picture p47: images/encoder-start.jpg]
start encoder


Take your time on this process.
The legs are fragile,
and you need to have all 7 legs in place before you press it through.
If some bend during this process, take a breath, bend them back, and try again.
The side legs are designed to hold the encoder in place,
so they will take a little force to get them through the board.

Once inserted, the encoder will remain firmly in place while you apply solder from the other side.

Solder all 7 legs.

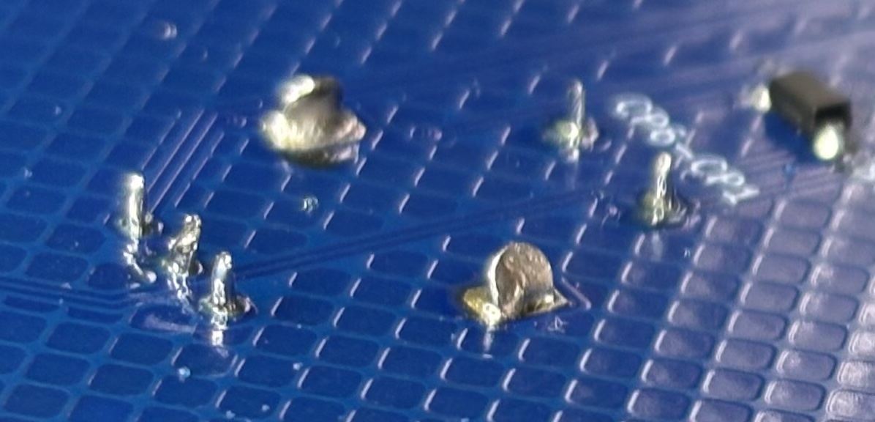
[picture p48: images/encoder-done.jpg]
encoder done


### Clean the board

Congratulations. You are done soldering all the components.

Use isopropyl alcohol and an old toothbrush to clean the extra flux from the board.

Take a moment and admire your work.

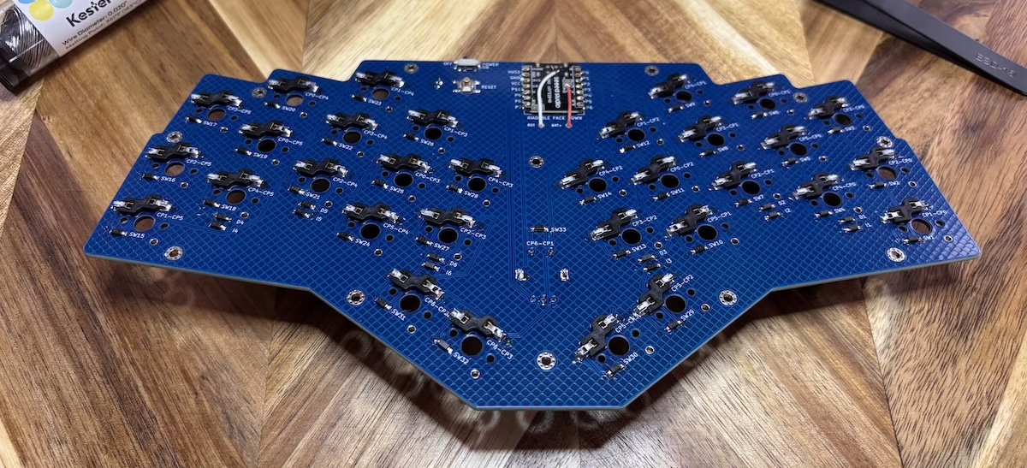
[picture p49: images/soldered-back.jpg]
back done


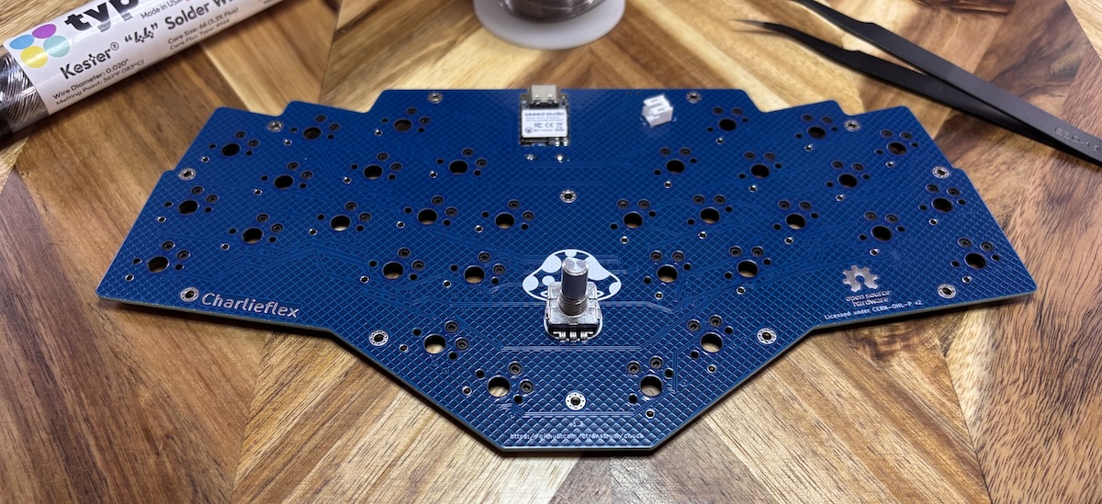
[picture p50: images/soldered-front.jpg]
front done


## Install the case

### Install the heat-set inserts

_Note_: you should skip this step if you are not building a wireless keyboard.
The heat-set inserts are used to attach the battery cover to the case,
which is not present in the wired version of the case.

While you can use your regular soldering tip for installing the heat-set inserts,
it is easier to get better results using a heat-set tip.

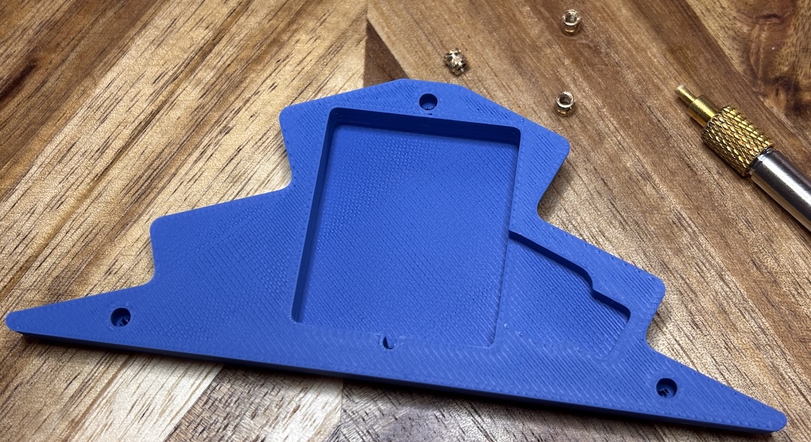
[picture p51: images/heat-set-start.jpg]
start heat-set


Place the heat-set insert above the hole, ensuring that the smaller side is down.
It can be a bit hard to see the different widths of each end,
so feel free to use a magnifier glass if needed.

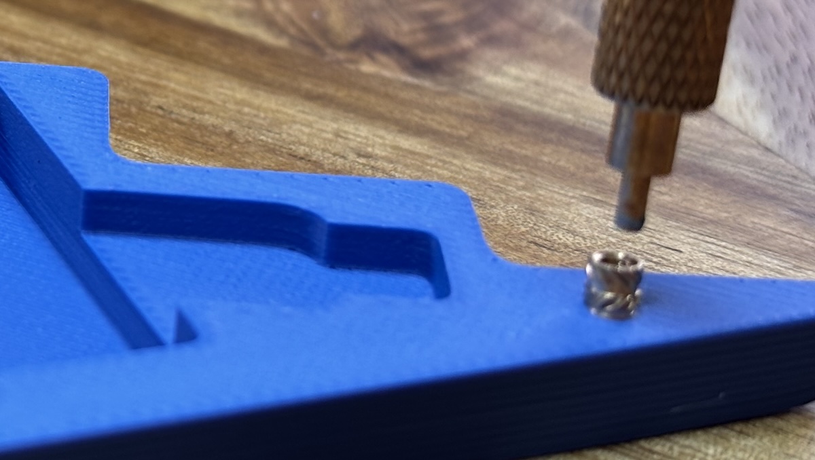
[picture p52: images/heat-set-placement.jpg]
heat-set placement


Place the heat-set tip into the heat-set insert and apply very gentle pressure
while the tip heats the insert.
The plastic will melt and the insert will glide into place.
Don't push it below the surface of the plastic.

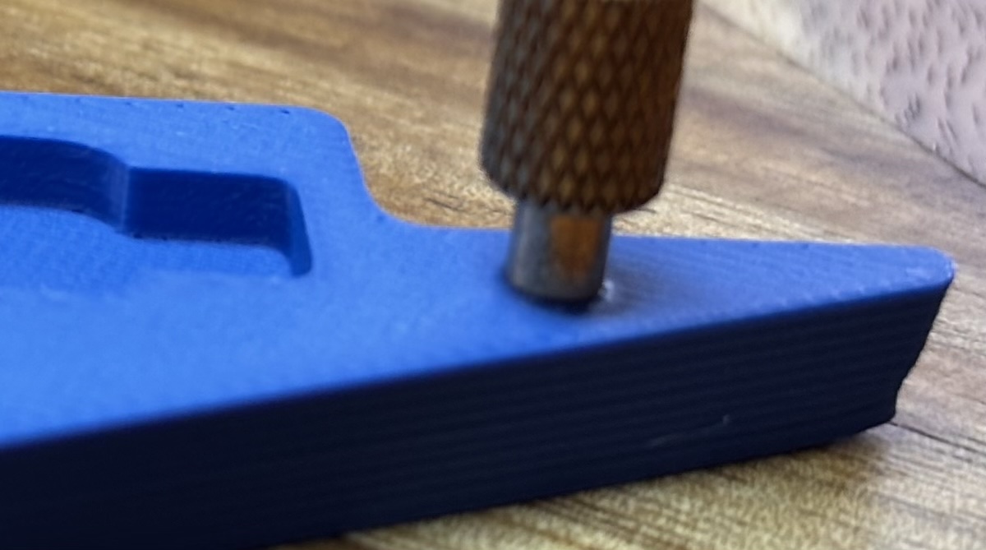
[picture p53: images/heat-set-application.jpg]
heat-set application


Repeat for the other two heat-set inserts.

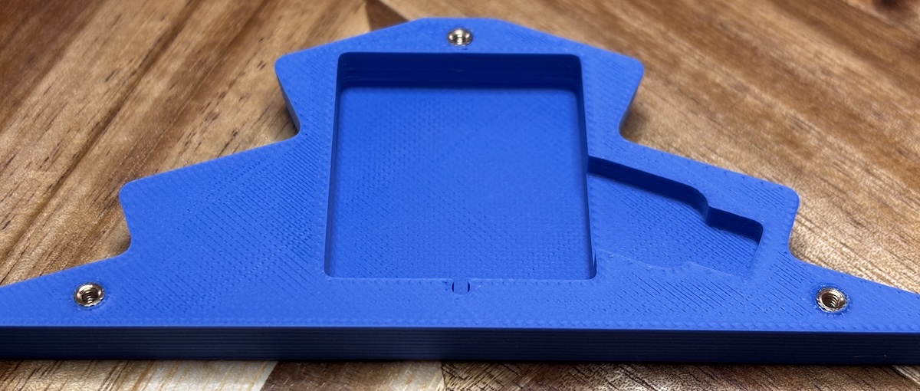
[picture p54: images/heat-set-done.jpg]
heat-set complete


### Top plate

Set the top plate upside down and insert the hex nuts into place in the case.
Note that there are 9 hex nuts used for the wireless case, and 12 for the wired version.
If you are using the rectangle case, you will use only one hex nut for this step.

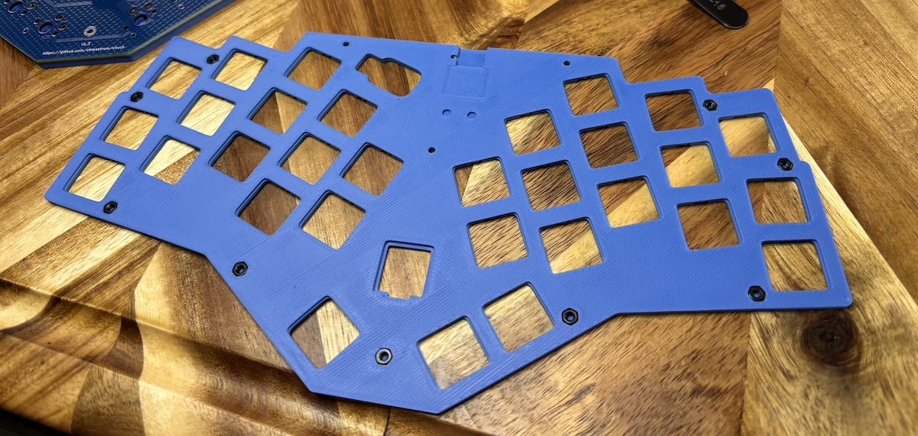
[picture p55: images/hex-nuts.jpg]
hex nuts


Carefully lift the top plate from the table,
and while holding it upside down so that the hex nuts do not fall,
insert the completed board into place.
The encoder knob and the JST connector will extend below the board,
so it can help to take a couple of books to support each side of the board
in preparation for the next step.

### Bottom case

Place the bottom of the case upside down in place on the exposed bottom of the board.
Insert and secure the nine 6mm countersunk screws.
Three on the left side, three on the right side, and three on the bottom.
If using the rectangle case, there is just a single screw needed at the bottom center.

For the wireless build,
leave the center screw hole and the two top screw holes empty for now.

For the wired build, insert those three 6mm countersunk screws at this time as well.

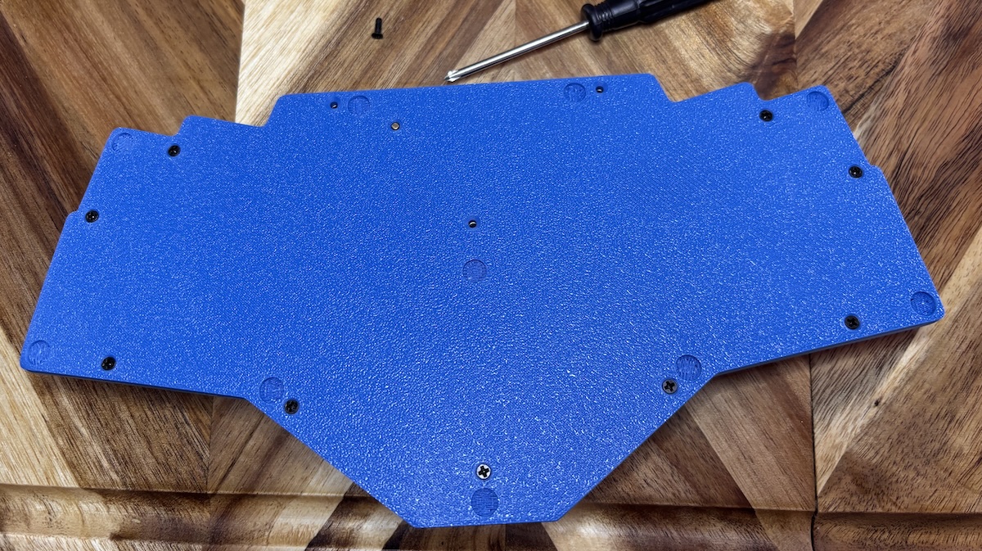
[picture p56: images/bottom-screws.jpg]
bottom screws


### Battery

_Note_: you should skip this step if you are not building a wireless keyboard.

Insert the battery JST cable into the JST connector,
carefully observing the polarity of the wires.

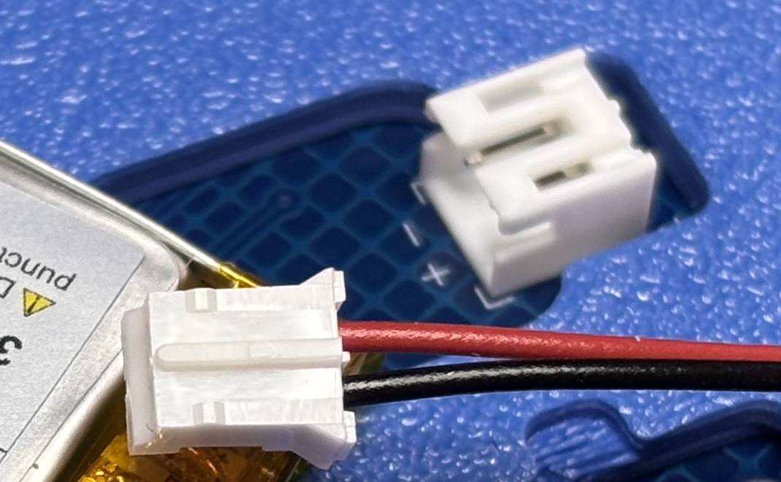
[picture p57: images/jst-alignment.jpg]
jst alignment


The red wire should always connect to the + symbol on the board,
and the black wire to the - symbol.
If your battery cable is wired incorrectly, stop now and replace
the wire or buy a different battery.

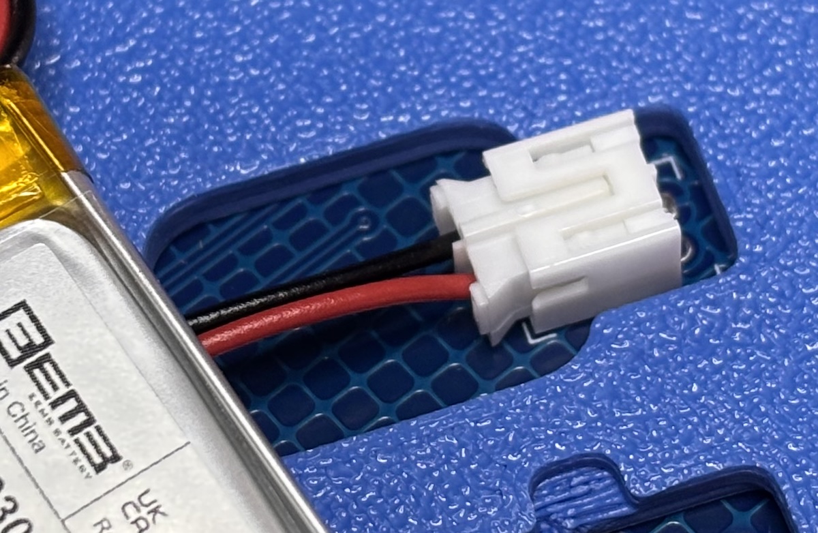
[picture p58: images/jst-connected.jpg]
jst connected


### LED light guide

Cut a piece of transparent filament about 1cm in length for a wireless build
or about 2.5 to 3 mm in length for a wired build.
Ensure that it can be inserted into the LED light guide hole.
Tolerances on 3D prints are not always great,
so you may need to slightly enlarge the hole,
or if the hole is too loose,
you may need to apply a small amount of glue when installation is complete.

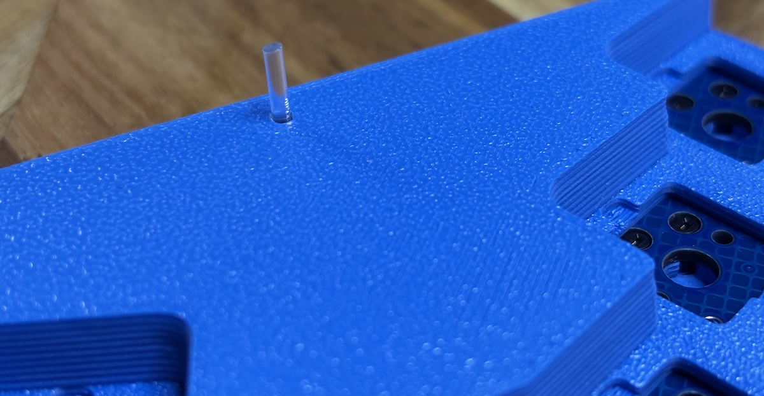
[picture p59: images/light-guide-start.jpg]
light guide start


If using the battery cover for a wireless build,
test the length of the filament by inserting it through the battery cover and
into its place in the top case.
I like to do this before the battery cover is installed so that I can more easily
work with the filament and the holes as needed.

If instead you are doing a wired build,
the correct fit is easier to determine,
though the small length of filament can be trickier to work with.

Ensure that the filament is flush or slightly protrudes maybe half a millimeter when fully inserted.

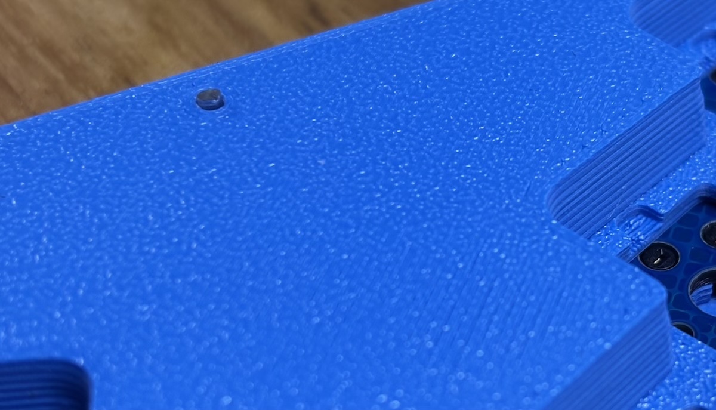
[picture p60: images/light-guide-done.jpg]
light guide complete


This filament will bring the light from the LED on the XIAO up to the top surface of the case.

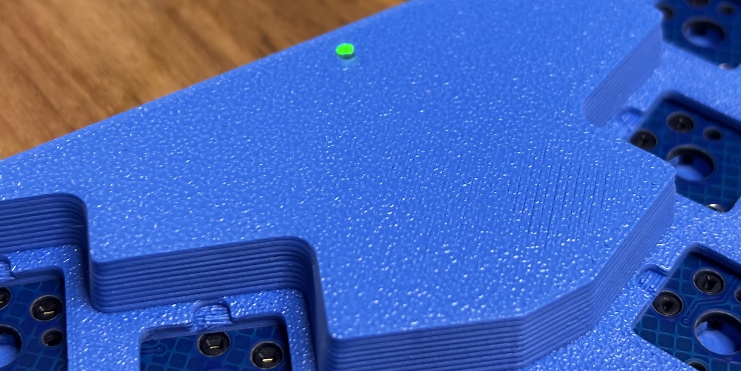
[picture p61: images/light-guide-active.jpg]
light guide active


### Battery cover

_Note_: you should skip this step if you are not building a wireless keyboard.

Finally, arrange the battery and wires in place so that the battery cover can close,
and then insert the three 10mm countersunk screws through the bottom of the case to secure the battery cover.

### Knob cover

Add the knob by aligning the grooves on the encoder, and pressing it firmly into place.

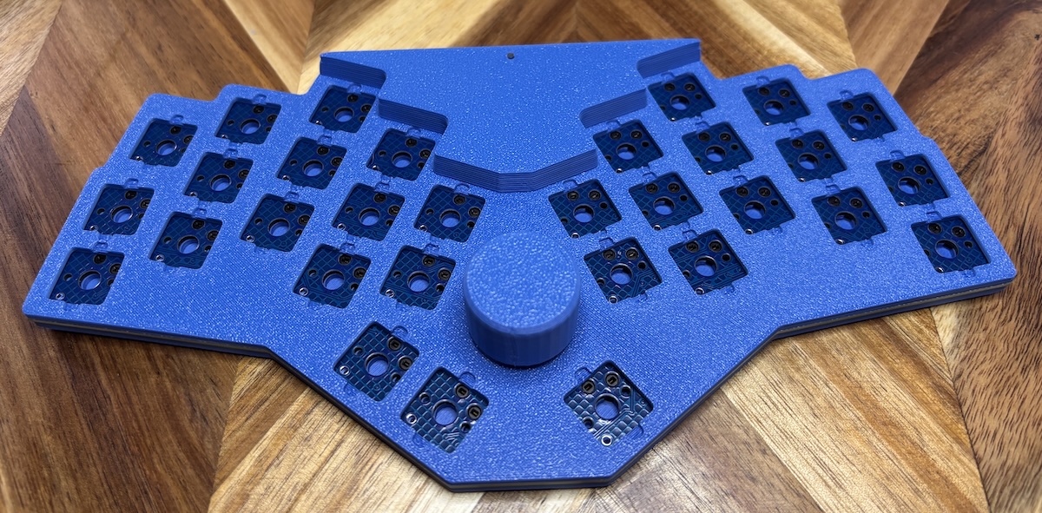
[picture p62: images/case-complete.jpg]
case complete


### Switches and keycaps

Take care when inserting the switches that the pins of each switch are straight.
Gently place the switch in place, and position it so it is aligned before pushing it
straight down. Do not try to assemble it at an angle. It may take a bit of force to get the
switch fully seated. There should be no gap between the skirt of the switch and the top plate.

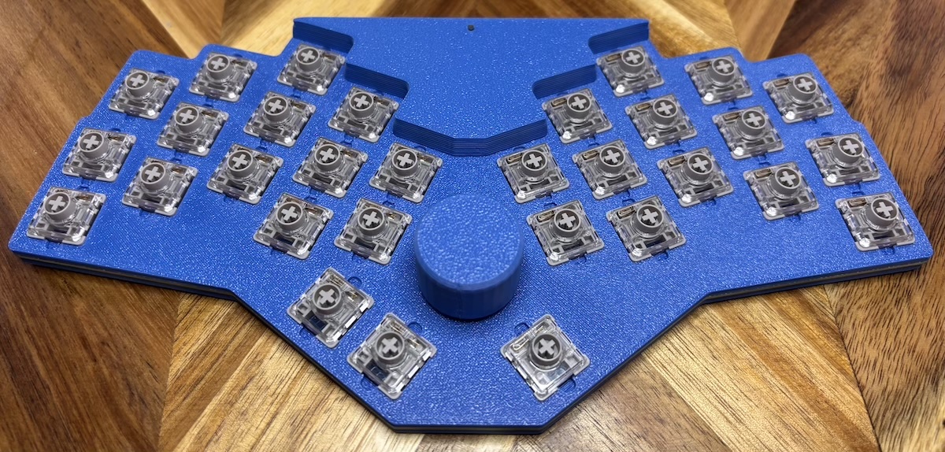
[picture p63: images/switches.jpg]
switches installed


Attach the keycaps. Again, try to first align the keycap and then use firm even pressure.

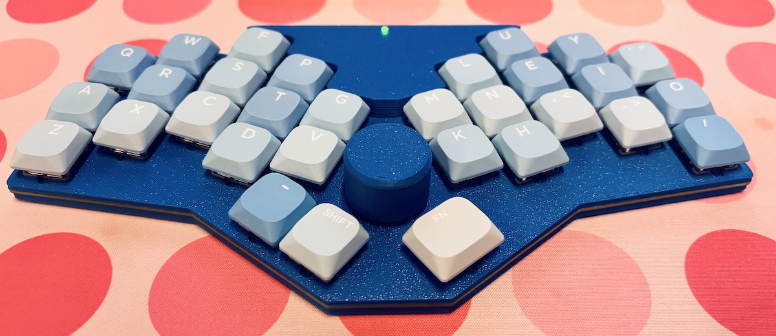
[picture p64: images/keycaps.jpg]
keycaps installed


### Attach the bumpons

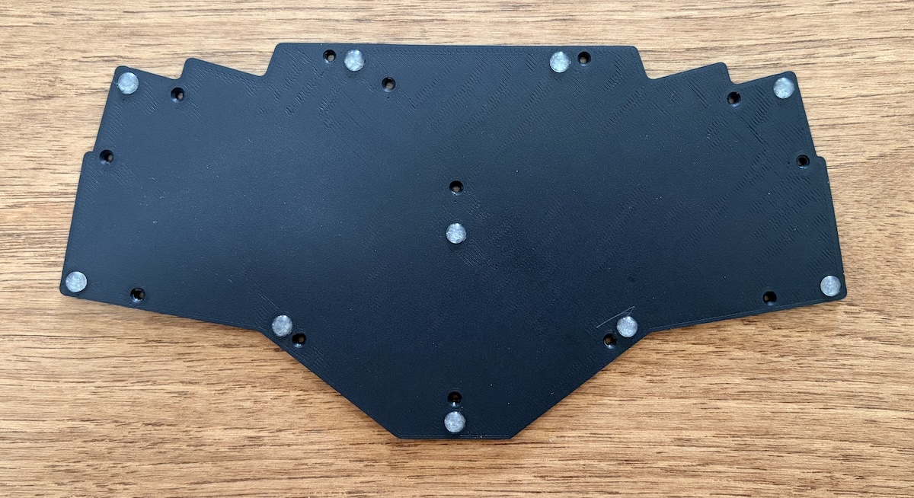
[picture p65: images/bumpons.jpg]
location of bumpons


Once everything else is installed, flip the keyboard back over and press each bumpon into place
in its designated spot. Your keyboard is now ready for its photoshoot and the installation of firmware.

## Photoshoot

If you'd like to share your hard work with the rest of the world, take a photo of your new Charlieflex and
send it to me. My contact information is on my profile. Congratulations on a job well done!

## Firmware installation

You can grab the default firmware from the [firmware repository][firmware].

To install it, attach the keyboard to the computer by USB,
double-tap the reset button on the bottom of the board,
and then drag the appropriate firmware
to the new device that appears as a thumb drive on the computer's file manager.

drag and drop to install

Note, however, that the "thumb drive" is not actually a real thumb drive, and normal copy and paste operations
do not work as they do on a real thumb drive. Copying the file to the keyboard is really a command to the
microcontroller to install firmware. As soon as the firmware is installed, the keyboard will reboot and start
running the new firmware. This will make the "thumb drive" immediately disconnect from the computer, which
is often seen as an error by the operating system.

ignore read/write error

But you are free to ignore that error and just start using the keyboard. Just don't try to copy anything that's
not a firmware to the keyboard, and you should be fine.

## Problems?

For more information about using [ZMK][zmk], including how to use [ZMK Studio][zmkstudio],
or how to configure your own [zmk repo][zmkrepo], please refer to the [ZMK docs][zmkdocs].

If you still have the default keymap installed and want to update the layout with [ZMK Studio][zmkstudio],
the "ZMK Studio unlock" key combination is accessed
by simultaneously pressing the top two keys on the outside edges of the keyboard,
or in other words, the keys that are by default mapped to Q and apostrophe.
Note that as of the time of this writing, you will need to be using Chrome or Edge to get it to work.

If a single key isn't working,
the first thing to look at is that the switch has been installed properly,
and the pins aren't bent.
The second most likely cause of a single key not working is an improperly installed diode.
Find the diode closest to that key and ensure it is installed in the correct orientation
and that both legs are well attached to the PCB.

If you need to troubleshoot the soldering by shorting MCU pins to test the firmware is working,
note that this board uses a charlieplex matrix with an interrupt pin,
so you will not be able to test by shorting only the row/column pins together
as you would in a standard matrix wiring diagram.
Instead, you will also need to connect to the interrupt pin as well,
which is labeled as P7 on the PCB.

The pins used for each switch is printed on the PCB next to the switch.
An example label would be something like `CP0-CP5`,
which means that the switch connects P0 to P5.
So to test that switch by shorting wires together,
you would need to short P0 (the source pin)
to both P5 (the destination pin)
as well as P7 (the interrupt pin).

The encoder keypress is wired up the same as any other key,
using a source pin, a destination pin, and the interrupt pin.
Turning the encoder left and right is handled via pins P8 and P9 on the MCU.

P10 is not used.
If one MCU pin becomes damaged,
it may be possible to repair by connecting a jumper from the broken pin
to P10, and then updating the firmware to use P10 instead of the broken pin.

If you need to correct any soldering,
access to the bottom of the PCB involves removing all 12 screws from the bottom of the case.
You do not necessarily need to remove all the switches.
However, if you are doing extensive re-soldering work,
it may be a good idea to fully remove the PCB from the case.
This will prevent the heat from the soldering iron from deforming the case.

One unexpected feature of the XIAO BLE microcontroller is that the power switch must be "ON"
in order for the battery to charge while plugged into a USB-C cable.
An easy way to remember: sliding the power switch toward the USB port turns the keyboard on,
while sliding it away from the USB port turns it off.

[bambu]: https://makerworld.com/en/models/1367965-case-for-the-charlieflex-keyboard
[battery]: https://ydlbattery.com/products/3-7v-300mah-502530-lithium-polymer-ion-battery
[bumpons]: https://www.walmart.com/ip/Small-Door-Bumpers-Self-Adhesive-Clear-Rubber-Feet-Tiny-Bumpons-1-4-Diameter-X-1-16-Thick-100-Pack-u2026/2377364014
[case]: cases#readme
[case-knob]: cases#encoder-knobs
[chockeycaps]: https://lowprokb.ca/collections/keycaps/products/ldsa-low-profile-blank-keycaps
[chocv1]: https://lowprokb.ca/collections/switches/products/ambients-silent-choc-switches
[chocv2]: https://www.lofree.co/products/hades-low-profile-pom-switches
[encoder]: https://www.mouser.com/ProductDetail/Bourns/PEC11L-4115F-S0020?qs=gk21WLQFtgRAgrgJZfpkWw%3D%3D
[filament]: https://gizmodorks.com/nylon-filament-200-g-spool/
[firmware]: https://github.com/ctranstrum/chuck/tree/zmk
[gerber]: pcb/chuck-gerbers.zip
[heatset]: https://www.partsbuilt.com/m2-heat-set-thread-insert-3mm-wide-3mm-long-4-pack/
[heatsettool]: https://pine64.com/product/pinecil-threaded-insert-tips-set-and-adapter/
[hexnuts]: https://www.getfpv.com/m2-black-metal-hex-nut-set-of-8.html
[how-to-solder]: https://www.google.com/search?q=youtube+how+to+solder
[jlc3dp]: https://jlc3dp.com/
[jlcpcb]: https://jlcpcb.com/
[jst]: https://typeractive.xyz/products/battery-jack
[kester]: https://typeractive.xyz/products/kester-solder-wire-tube
[mxkeycaps]: https://nuphy.com/collections/keycaps/products/numoji-nsa
[pcb]: pcb/
[pinecil]: https://typeractive.xyz/products/pinecil
[power]: https://typeractive.xyz/products/power-switch
[pts526]: https://www.ckswitches.com/media/2780/pts526.pdf
[reset]: https://www.aliexpress.us/item/3256806760201032.html
[screws6mm]: https://monsterbolts.com/products/mach-phil-flat-a2-m2?variant=21222571802707
[screws10mm]: https://monsterbolts.com/products/mach-phil-flat-a2-m2?variant=21222572064851
[smallencoder]: https://www.mouser.com/ProductDetail/Bourns/PES12-42S-N0024?qs=9fn1gpisni7dJzyRXeQZlQ%3D%3D
[sockets]: https://typeractive.xyz/products/hotswap-sockets?variant=45742200324327
[sod123]: https://typeractive.xyz/products/smd-diodes
[soldering101]: https://www.google.com/search?q=youtube+soldering+101
[splitkb-build-guide]: https://docs.splitkb.com/product-guides/aurora-series/build-guide
[ts18]: https://www.sameskydevices.com/product/resource/ts18.pdf
[wire]: https://www.walmart.com/ip/26-Gauge-PVC-Hookup-Wire-1-5m-5ft-26AWG-Flexible-Electrical-Wire-Tinned-Copper-Stranded-6-Color-1-5mm/5487030958
[xiao]: https://wiki.seeedstudio.com/XIAO_BLE/
[rp2040]: https://wiki.seeedstudio.com/XIAO-RP2040/
[zmk]: https://zmk.dev
[zmk-xiao]: https://zmk.dev/docs/hardware#seeed_xiao
[zmkdocs]: https://zmk.dev/docs
[zmkrepo]: https://zmk.dev/docs/user-setup
[zmkstudio]: https://zmk.studio/

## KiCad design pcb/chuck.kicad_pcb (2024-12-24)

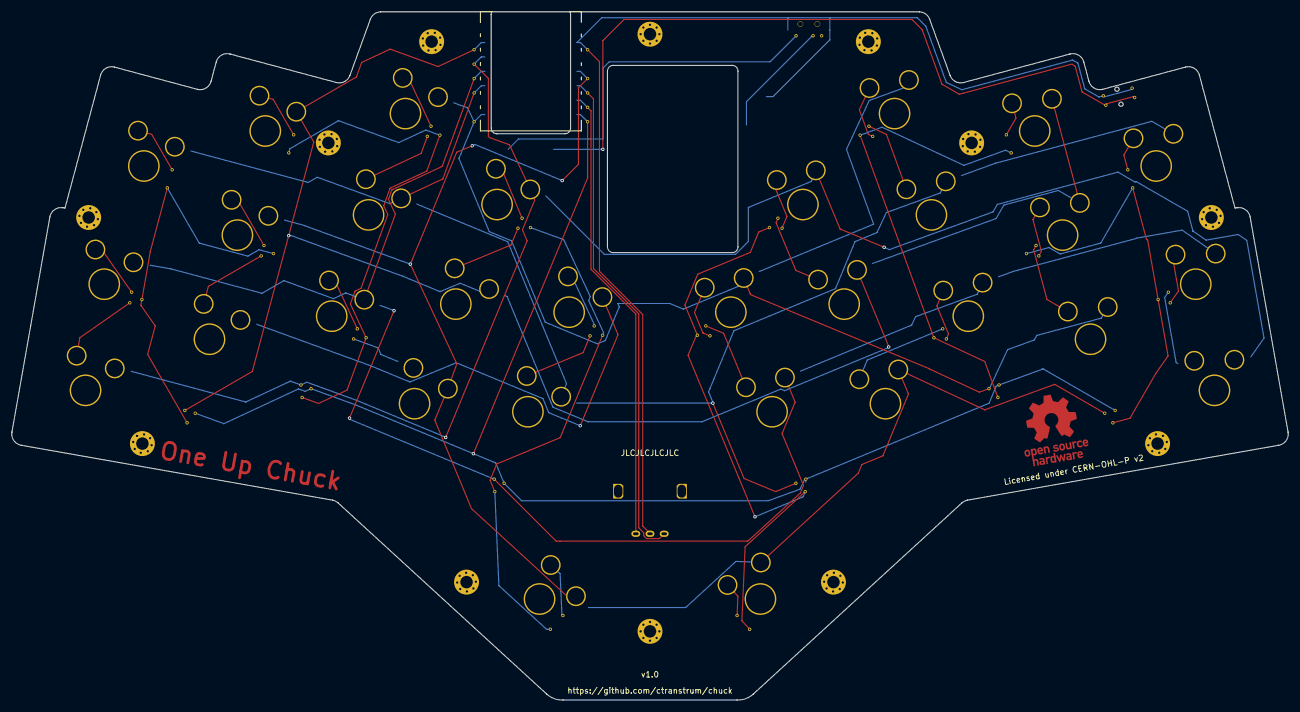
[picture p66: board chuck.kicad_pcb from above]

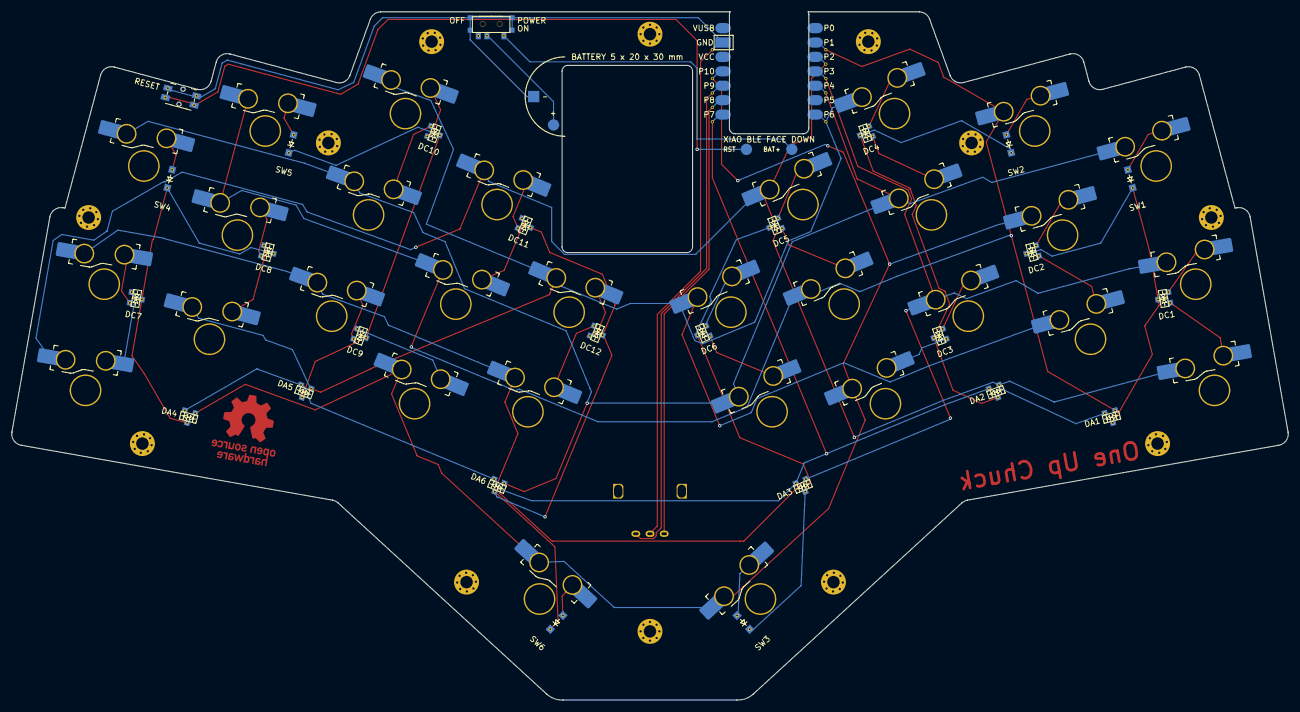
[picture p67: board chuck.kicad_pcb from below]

Board: 2 copper layers, 225.0 x 121.3 mm, 63 parts (54 on the bottom side), 49 nets.

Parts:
ARC1: arc_guide
B1: Panasonic_EVQPUL_EVQPUC
DA1, DA2, DA3, DA4, DA5, DA6: ComboDiode
DC1, DC2, DC3, DC4, DC5, DC6, DC7, DC8, DC9, DC10, DC11, DC12: ComboDiode
ENC1: rotary_encoder_ec11_ec12
MCU1: xiao-ble
PAD1, PAD2, PAD3, PAD4: SMDPad
S1, S2, S3, S4, S5, S6, S7, S8, S9, S10, S11, S12, S13, S14, S15, S16, S17, S18, S19, S20, S21, S22, S23, S24, S25, S26, S27, S28, S29, S30: switch_gateron_ks27_ks33
SW1, SW2, SW3, SW4, SW5, SW6: ComboDiode
T1: SPDT_C128955

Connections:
BAT+: PAD1.1, T1.1
CP0: DA1.2, MCU1.2, MCU1.16, S6.1, S11.1, S19.1, S20.1, S25.1
CP1: DA2.2, MCU1.3, MCU1.17, S1.1, S12.1, S15.1, S26.1
CP2: DA3.2, MCU1.4, MCU1.18, S2.1, S7.1, S16.1, S21.1, S27.1
CP3: DA6.2, MCU1.5, MCU1.19, S3.1, S8.1, S13.1, S17.1, S22.1
CP4: DA5.2, MCU1.7, MCU1.20, S4.1, S9.1, S14.1, S18.1, S23.1, S28.1
CP5: DA4.2, MCU1.11, MCU1.24, S5.1, S10.1, S24.1, S29.1, S30.1
CP_INT: DA1.1, DA2.1, DA3.1, DA4.1, DA5.1, DA6.1, MCU1.8, MCU1.27
D_CP0: DA1.3, DC1.3, DC2.3, SW1.1
D_CP1: DA2.3, DC3.3, DC4.3, SW2.1
D_CP2: DA3.3, DC5.3, DC6.3, SW3.1
D_CP3: DA6.3, DC11.3, DC12.3, SW6.1
D_CP4: DA5.3, DC9.3, DC10.3, SW5.1
D_CP5: DA4.3, DC7.3, DC8.3, SW4.1
ENC_A: ENC1.A, MCU1.10, MCU1.25
ENC_B: ENC1.B, MCU1.9, MCU1.26
GND: B1.1, ENC1.C, MCU1.13, MCU1.22, PAD4.1
RAW: PAD3.1, T1.2
RST: B1.2, PAD2.1
index_bottom: DC3.2, S10.2
index_home: DC5.2, S11.2
index_top: DC5.1, S12.2
inner_bottom: DC6.2, S13.2
inner_home: DC6.1, S14.2
middle_bottom: DC3.1, S7.2
middle_home: DC4.2, S8.2
middle_top: DC4.1, S9.2
mirror_index_bottom: DC9.2, S24.2
mirror_index_home: DC11.2, S25.2
mirror_index_top: DC11.1, S26.2
mirror_inner_bottom: DC12.2, S27.2
mirror_inner_home: DC12.1, S28.2
mirror_middle_bottom: DC9.1, S21.2
mirror_middle_home: DC10.2, S22.2
mirror_middle_top: DC10.1, S23.2
mirror_pinky_bottom: DC7.2, S15.2
mirror_pinky_home: DC7.1, S16.2
mirror_pinky_top: S17.2, SW4.2
mirror_ring_bottom: DC8.2, S18.2
mirror_ring_home: DC8.1, S19.2
mirror_ring_top: S20.2, SW5.2
mirror_thumb_spot: S30.2, SW6.2
pinky_bottom: DC1.2, S1.2
pinky_home: DC1.1, S2.2
pinky_top: S3.2, SW1.2
ring_bottom: DC2.2, S4.2
ring_home: DC2.1, S5.2
ring_top: S6.2, SW2.2
thumb_spot: S29.2, SW3.2

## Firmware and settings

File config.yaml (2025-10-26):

meta:
  keyboard: &keyboard_name Charlieflex
  author: chad@transtrum.net
  version: &version v1.3
  repository: &repo https://github.com/ctranstrum/chuck
  license: &license Licensed under CERN-OHL-P v2

  # Depending on where you are ordering from, uncomment or edit one of these:
  # order_num_template: &order_text JLCJLCJLCJLC # for ordering from JLCpcb.com
  # order_num_template: &order_text WayWayWay    # for ordering from PCBway.com
  order_num_template: &order_text "" # remove the order number text completely

units:
  dx: u
  dy: u

  hdx: dx / 2
  hdy: dy / 2

  knob_diameter: 25
  # how far to drop the outside edge of the knob, knob diameter must be larger than 21
  knob_skirt: 2

  # EC11 knob height must be at least 16
  ec11_knob_height: 17
  ec11_shaft_height: 7

  # EC12 knob height must be at least 8.5
  ec12_knob_height: 16
  ec12_shaft_height: 2.65

  # easily change the thicknesses of different parts of the case
  bottom_case_height: 3
  top_case_height: 2.2
  attic_case_height: 7

  mirrored_distance: 1.75 dx

points:
  zones:
    matrix:
      # Shift the PCB down and to the right to get it on the sheet in kicad
      anchor.shift: [50, -100]
      mirror:
        ref: matrix_inner_home
        distance: mirrored_distance
      key:
        autobind: .5
        tags: [switch]
      columns:
        pinky:
          key:
            cpdst: CP0
            splay: -10
            mirror.cpdst: CP5
          rows:
            bottom:
              cpsrc: CP1
              bind: [0, 45, 0, 0]
              tags: [switch, low_bumper]
            home:
              cpsrc: CP2
              tags: [switch]
              shared: pinky_bottom
              mirror.shared: mirror_pinky_bottom
            top:
              orient: -5
              shift: [3, 3]
              cpsrc: CP3
              tags: [switch, high_bumper]
              bind: [0, 4]
        ring:
          key:
            stagger: 2/3 dx
            spread: 1.05 dx
            splay: -5
            cpdst: CP0
            mirror.cpdst: CP5
          rows:
            bottom:
              cpsrc: CP4
              tags: [switch, return]
            home:
              cpsrc: CP5
              tags: [switch]
              shared: ring_bottom
              mirror:
                cpsrc: CP0
                shared: mirror_ring_bottom
            top:
              cpdst: CP1
              cpsrc: CP0
              mirror.cpdst: CP4
              tags: [switch]
        middle:
          key:
            stagger: hdx
            spread: 1.04 dx
            splay: -5
            cpdst: CP1
            mirror.cpdst: CP4
          rows:
            bottom:
              cpsrc: CP2
              tags: [switch, return]
              shared: index_bottom
              mirror.shared: mirror_index_bottom
            home:
              cpsrc: CP3
            top:
              cpsrc: CP4
              tags: [switch, mid_bumper]
              bind: [0, 1]
              shared: middle_home
              mirror:
                cpsrc: CP1
                shared: mirror_middle_home
        index:
          key:
            stagger: -hdx
            splay: -2.5
            cpdst: CP2
            mirror.cpdst: CP3
          rows:
            bottom:
              cpdst: CP1
              cpsrc: CP5
              mirror.cpdst: CP4
            home:
              cpsrc: CP0
            top:
              cpsrc: CP1
              tags: [switch]
              shared: index_home
              mirror.shared: mirror_index_home
        inner:
          key:
            stagger: 2/3 hdx
            cpdst: CP2
            mirror.cpdst: CP3
          rows:
            bottom:
              cpsrc: CP3
              mirror.cpsrc: CP2
              tags: [switch, return]
            home:
              cpsrc: CP4
              tags: [switch]
              shared: inner_bottom
              mirror.shared: mirror_inner_bottom

    thumbs:
      mirror:
        ref: matrix_inner_home
        distance: mirrored_distance
      anchor:
        ref: matrix_inner_bottom
        shift: [0, -dy - 3]
      key:
        cpsrc: CP5
        mirror.cpsrc: CP6
        bind: [15, 0, 0, 15]
      columns:
        inner.rows.spot:
          splay: -15
          cpdst: CP2
          tags: [opt_switch]
        outer.rows.spot:
          cpdst: CP3
          tags: [switch]

    encoder:
      anchor:
        aggregate.parts: [thumbs_outer_spot, mirror_thumbs_outer_spot]
        shift: [0, 1.05 dy]
      key:
        tags: [encoder]
        cpsrc: CP6
        cpdst: CP1
        bind: [25, 4.3, 23.75, 4.3]

    mcu:
      key.tags: [mcu]
      anchor:
        # top middle left
        aggregate.parts: [matrix_middle_top, mirror_matrix_middle_top]
        shift: [-6, 2.65]

    power:
      key.tags: [power]
      anchor:
        aggregate.parts: [matrix_middle_top, mirror_matrix_middle_top]
        shift: [20, 13]
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

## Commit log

2024-12-24 Ready for first prototype
    [chuck.kicad_pcb]
2024-12-24 Added ground fill
    [chuck-B_Cu.gbr, chuck-B_Mask.gbr, chuck-B_Paste.gbr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]
2024-12-24 Gerber file ready
2024-12-24 Added bill of materials
2024-12-24 choice of xiao boards
2024-12-29 update info on bourns encoders for wireless builds
2024-12-31 begin work on the case
2025-01-03 update encoder cutouts in bottom case
2025-01-14 update PCB to v1.1, using correct diodes
    [chuck-B_Cu.gbr, chuck-B_Mask.gbr, chuck-B_Paste.gbr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]
2025-01-15 changing the order of building the case fixes the crazy geometry for some reason
    [config.yaml]
2025-01-19 add knob and dovetail top case
    [encoder_knob-10mm.stl, encoder_knob-13mm.stl, encoder_knob-15mm.stl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]
2025-01-19 add note for ergogen-generated stl files
2025-02-04 v1.2 of the board
    [ec11_encoder_knob.stl, ec12_encoder_knob.stl, encoder_knob.stl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]
2025-02-04 add the gerbers
    [chuck-B_Cu.gbr, chuck-B_Mask.gbr, chuck-B_Paste.gbr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]
2025-02-05 add space in the bottom case for the encoder switch pins
2025-03-11 PCB for v1.3 is sent off to be manufactured
    [chuck-B_Mask.gbr, chuck-B_Paste.gbr, chuck-B_Silkscreen.gbr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]
2025-03-11 update info for v1.3 of the board
2025-04-07 update cases models for v1.3 of the board
    [attic.stl, ec11_encoder_knob.stl, ec12_encoder_knob.stl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]
2025-04-07 missed attic screws on bottom case
    [config.yaml]
2025-04-09 update information on battery
2025-04-11 add case options for different number of thumb keys
    [bottom_dovetail_left.stl, bottom_dovetail_right.stl, top_dovetail.stl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]
2025-04-11 add printing hints
2025-04-11 add printing hints for encoder knobs as well
2025-04-12 add additional case / build information
2025-05-01 Add sample photo of a completed Charlieflex
2025-05-13 update bom
2025-06-26 design case specifically for a wired build
    [top_dovetail.stl, top_dovetail_left_1.stl, top_dovetail_left_2.stl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]
2025-07-03 Additional notes for a wired build
2025-10-14 testing a block case
    [attic.stl]
2025-10-23 look at a snap fit case option
2025-10-24 test a snap-fit type case
    [attic.stl, top_dovetail.stl, top_dovetail_left_1.stl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]
2025-10-26 Finalize the snap-fit case
2025-11-11 Rectangle case photos
2025-11-11 more case pictures
2025-11-11 full size case sample photos
2025-11-11 add finger map
2025-11-11 use an svg for finger placement
